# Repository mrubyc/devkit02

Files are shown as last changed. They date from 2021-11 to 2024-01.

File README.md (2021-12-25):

# ITOC謹製 mruby/c 開発ボード02

for mruby/c development kit 02 by ITOC.

## What is ?

ITOC (https://www.s-itoc.jp) で作成した mruby/c 開発リファレンスボード用リポジトリ。

マイコンは、Cypress PSoC5LP (CY8C5888LTI-LP097) であり、同社製のキット CY8CKIT-059 のピギーバックしているだけなので、素の CY8CKIT-059 に書き込んでも使える。

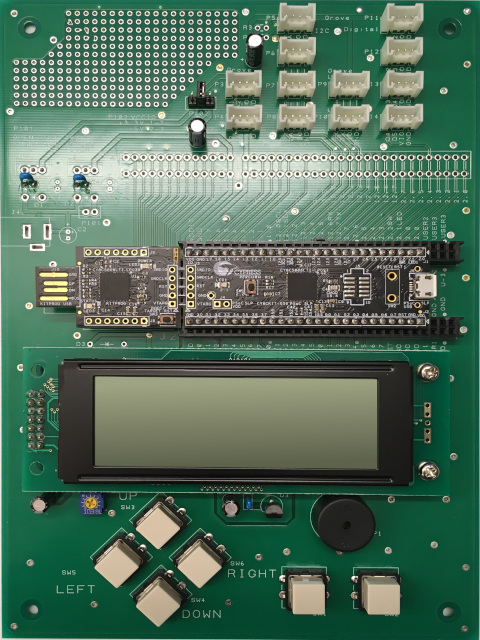
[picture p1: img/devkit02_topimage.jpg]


## Related Link

### Download IDE and others.
https://www.s-itoc.jp/activity/research/mrubyc/mrubyc_download/

### mrbwrite source code.
https://github.com/mrubyc/mrbwrite

### IDE source code.
comming soon.

### Device class source code.

https://github.com/mrubyc/dev

and I/O API proposal

https://github.com/mrubyc/dev/blob/master/mrubyc_io_api.md

### mruby/c sample code.

Some sample programs that mainly control sensors.

https://github.com/mrubyc/devkit02/tree/main/samples

## LICENSE

  Copyright (C) 2015-2021 Shimane IT Open-Innovation Center.

  All files in this repository are distributed under BSD 3-Clause License.

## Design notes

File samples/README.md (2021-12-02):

# Samples

mruby/c code sample with mruby/c devkit 02.

* GPIO
* A/D
* I2C with many sensors.

Most sensor sample programs work well on the Raspberry Pi.

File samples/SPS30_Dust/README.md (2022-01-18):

# SENSIRION SPS30

PM2.5 Sensor for HVAC and air quality applications

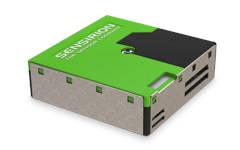
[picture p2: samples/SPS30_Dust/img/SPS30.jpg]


https://sensirion.com/products/catalog/SPS30/

## Connect to the board.

Connect to the glove I2C connector with a handmade bulk cable.

## Sample program

1. Use the I2C interface.
2. Reads PM2.5 and other size particle about once every second.
3. Display each measured value on the LCD panel (with scroll).

## Demo

https://user-images.githubusercontent.com/16683312/149897055-d63019b6-a0ee-472d-b40c-353299b3132d.mp4

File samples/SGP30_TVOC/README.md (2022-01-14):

# SENSIRION SGP30

Indoor Air Quality Sensor for TVOC and CO2eq Measurements

https://www.sensirion.com/en/environmental-sensors/gas-sensors/sgp30/

## Breakout board

to Grove connector; Seeed studio 101020512

https://www.seeedstudio.com/Grove-VOC-and-eCO2-Gas-Sensor-for-Arduino-SGP30.html

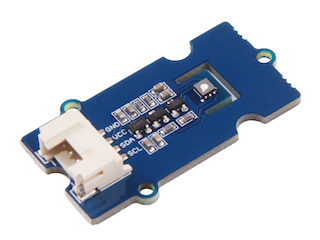
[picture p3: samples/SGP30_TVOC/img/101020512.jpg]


## Sample program

1. Use the I2C interface.
2. At first, wait 15 seconds for initializing sensor.
3. Reads VOC(TVOC) and CO2eq about once every second.

## Demo

https://user-images.githubusercontent.com/16683312/149466663-6540f6f8-e14d-4b3b-be49-4e50278e2f83.mp4

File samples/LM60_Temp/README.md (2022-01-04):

# Texas Instruments LM60

Temperature sensor.

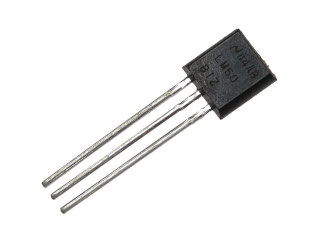
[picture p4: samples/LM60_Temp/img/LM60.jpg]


https://www.ti.com/product/LM60

mruby/c devkit 02 has LM60 temperature sensor on board.
This sensor has an analog output. 6.25 mV / ℃.

## Demo

https://user-images.githubusercontent.com/16683312/148042677-bf6fb1df-8735-4118-a3bd-9490f77eb376.mp4

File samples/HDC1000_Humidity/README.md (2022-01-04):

# Texas Instruments HDC1000

Digital Humidity Sensor with Integrated Temperature Sensor.

https://www.ti.com/product/HDC1000

## Breakout board

AkizukiDenshi AE-HDC1000.

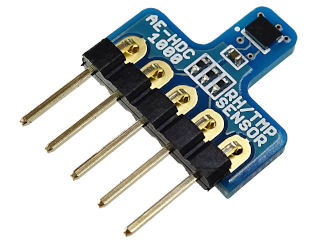
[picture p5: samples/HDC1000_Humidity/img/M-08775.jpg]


Connect a grove connector with soldering.

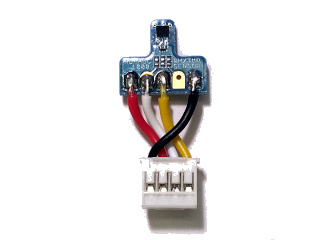
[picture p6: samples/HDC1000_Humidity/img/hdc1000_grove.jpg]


## Connect to the board.

Connect to the glove I2C connector.

## Sample program

1. Using I2C interface.
2. Reads temperature and humidity about once every second.

## Demo

https://user-images.githubusercontent.com/16683312/148039185-1c55f5a6-92fc-44ba-bbd0-9b33a6fce8e5.mp4

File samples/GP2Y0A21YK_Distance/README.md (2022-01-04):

# SHARP GP2Y0A21YK

Distance Measuring Sensor Unit.  
Measuring distance: 10 to 80 cm.  
Analog output type.

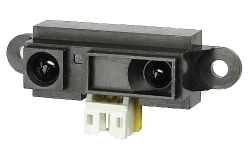
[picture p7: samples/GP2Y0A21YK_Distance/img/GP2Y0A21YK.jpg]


https://global.sharp/products/device/lineup/selection/opto/haca/diagram.html

## Connect to the board.

Connect to the glove analog connector with a handmade bulk cable.

## Sample program

1. Using Analog (A3) port.
2. Reads data with A/D API and display voltage value.
3. Also, when the voltage exceeds the threshold, LED1 is turned on to indicate that there is an object nearby. 

## Demo

https://user-images.githubusercontent.com/16683312/147382188-d99ca31b-5f03-4c57-91c4-038a6deff579.mp4

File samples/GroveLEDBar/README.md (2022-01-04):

# seeed studio Grove LED Bar v2.0

10 Segment LED Display using MY9221 12-Channel LED Driver

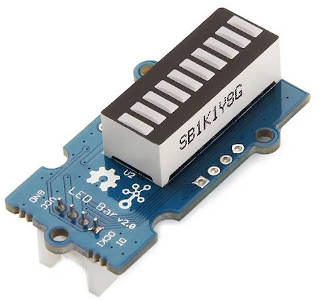
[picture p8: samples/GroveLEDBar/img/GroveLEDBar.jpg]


https://www.seeedstudio.com/Grove-LED-Bar-v2-0.html

## Sample program

Use as a level meter.
Also can specify the brightness of each LED individually.

## Demo

https://user-images.githubusercontent.com/16683312/147387371-79154d6b-c8f0-4d2c-b3c8-a75928846ea7.mp4

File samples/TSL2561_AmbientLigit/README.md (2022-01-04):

# ams (TAOS) TSL2561

Ambient Light Sensor

https://ams.com/tsl2561

## Breakout board

to Grove connector; Seeed studio 101020030

https://www.seeedstudio.com/Grove-Digital-Light-Sensor-TSL2561.html

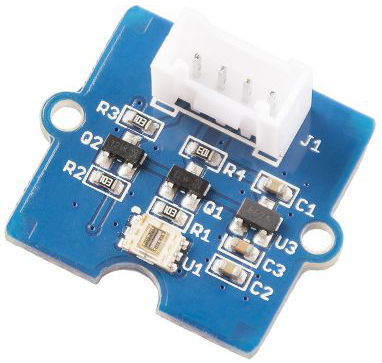
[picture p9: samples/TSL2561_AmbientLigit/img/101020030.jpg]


## Sample program

1. Use the I2C interface.
2. Use integration time 402ms and 101ms mode. (13.7ms mode is not used)
3. Automatically adjusts gain and integration time.

## Demo

https://user-images.githubusercontent.com/16683312/147381110-c7b632e3-6dce-4066-997e-5617c569e161.mp4

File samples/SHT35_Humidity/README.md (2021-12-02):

# Sensirion SHT35

Humidity and Temperature Sensor

https://www.sensirion.com/en/environmental-sensors/humidity-sensors/digital-humidity-sensors-for-various-applications/

## Breakout board

to Grove connector; Seeed studio 101020592

https://www.seeedstudio.com/Grove-I2C-High-Accuracy-Temp-Humi-Sensor-SHT35.html

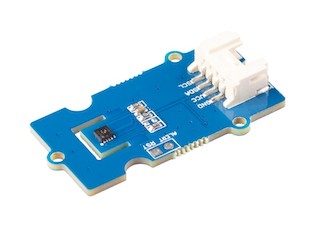
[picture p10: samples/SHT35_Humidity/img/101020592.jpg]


## Sample program

1. Using single shot mode with High repeatability clock stretching mode.
2. Reads about once every second.

## Demo

https://user-images.githubusercontent.com/16683312/144450023-0f474026-9f5d-40d5-b7ea-4d4efb06ff8f.mp4

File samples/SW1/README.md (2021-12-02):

# CY8C5888LTI-LP097 onboard switch SW1 ON and OFF demo.

## Abstruct

Cypress PSoC5LP Evaluation board CY8C5888LTI-LP097 onboard switch demo.

State of SW1 can be read by mruby/c method `sw1_read()`.

`sw1_read()` returns 0 when SW1 is pressed.

## Sample program

LED1 turns on when SW1 is pressed and turns off when released. 

## Demo

https://user-images.githubusercontent.com/16683312/144449586-0207ba0a-1b79-48ee-b7c4-c1c7ad308784.mp4

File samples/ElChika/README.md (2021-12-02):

# CY8C5888LTI-LP097 blink onboard LED.

## Abstruct

Cypress PSoC5LP Evaluation board CY8C5888LTI-LP097 onboard LED demo.

Blinking LED is often referred to as "el-chika" in Japan.

## Demo

https://user-images.githubusercontent.com/16683312/144448642-cc690b8e-6e4c-463b-ac18-35c6d1983098.mp4

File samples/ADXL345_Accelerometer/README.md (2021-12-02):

# ANALOG DEVICES ADXL345

Digital Accelerometer.

https://www.analog.com/en/products/adxl345.html

## Breakout board

https://akizukidenshi.com/catalog/g/gM-06724/

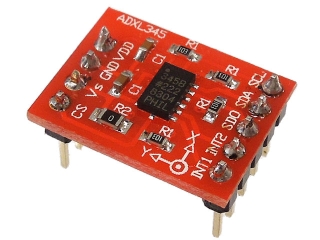
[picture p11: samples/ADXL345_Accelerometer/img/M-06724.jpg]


Set it on the breadboard and connect it to the glove connector with bulk wire.

## Sample program

1. Using I2C Interface.
2. Using Full resolution (16bit) mode.
3. Using ±2g measurement mode.

In one sample program, the measured value is represented by a bar that expands and contracts.

Another sample program simply emulates a ball rolling on a plane.

## Demo

main.rb

https://user-images.githubusercontent.com/16683312/144192729-ab362cf6-4b65-4aec-a082-47165c4c2c3b.mp4

main2.rb

https://user-images.githubusercontent.com/16683312/144194505-38d72f12-8f72-45bc-8e72-b4f3f158f905.mp4

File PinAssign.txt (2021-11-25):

[OnBoard]
LED1			P2[1]
SW1			P2[2]
Keypad			P0[0:5]
LCD			P15[0:5]
Thermo LM60		P3[0]
BUZZER			P3[6]
USB		Dm	P15[7]
		Dp	P15[6]
CONS		Rx	P12[6]
		Tx	P12[7]
SPI_1		MOSI	P1[2]
		MISO	P1[3]
		SCLK	P1[4]
		SS	P1[5]

[Grove]
ADC_SAR_1	Ana1	P3[1]
		Ana2	P3[3]
		Ana3	P3[5]

I2C_1		SCL	P12[0]
		SDA	P12[1]

UART_1		RX	P12[2]
		Tx	P12[3]

UART_2		RX	P12[4]
		Tx	P12[5]

GPIO		D1	P0[6]
		D2	P0[7]
		D3	P2[3]
		D4	P2[4]
		D5	P2[5]

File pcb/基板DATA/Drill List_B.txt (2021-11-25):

NC Drill Output
===============

    Output:
    ----------------------------
    Plated Round Drill Holes
    Unplated Round Drill Holes
    Plated Slots
    Unplated Slots

    Tool   Size        Count    ID   (Plated/Unplated)
    --------------------------------------------------
TH(スルーホール)
下記の穴径は、スルーホールメッキ後のサイズです。
穴径の公差指定の無い物は貴社の基準公差でお願いします。

    T001   000.300 mm  55     B
    T002   000.600 mm  26     I
    T003   000.601 mm  6      AI
      穴径0.6mmm でお願いします。

    T004   000.800 mm  273    O
    T005   000.801 mm  182    P
      J1,J2,J3,P3～P14のコネクタ用スルーホールです。
      穴径0.9mmm±0.1mm
      穴間公差±0.1mm でお願いします。

    T006   001.000 mm  5      E
    T007   001.001 mm  78     H
      穴径1.0mmm でお願いします。

    T008   001.002 mm  79     AH
      穴径1.0mmm でお願いします。

    T009   001.003 mm  2      AG
      SP1リード用スルーホール
      穴径1.0mmm±0.1mm でお願いします。
      穴間公差±0.1mm でお願いします。

    T010   001.010 mm  49     AF
      J4コネクタ用スルーホール(長穴)
      穴径1.0mmx3.2mm±0.1mm でお願いします。
      J4の他の穴間公差±0.1mm でお願いします。

    T011   001.011 mm  29     AX
      J4コネクタ用スルーホール(長穴)
      穴径1.0mmx3.8mm±0.1mm
      J4の他の穴間公差±0.1mm でお願いします。

    T012   001.200 mm  10     AE
    T013   001.201 mm  24     F
      SW1～6のリード用スルーホール
      穴径1.2mmm±0.1mm
      穴間公差±0.1mm でお願いします。

NTH(ノンスルーホール)
    T014   001.801 mm  12     G
      SW1～6の位置決め用の穴
      穴径1.90mm±0.1mm
      穴間公差9.0±0.1mm でお願いします。

    T015   003.200 mm  4      AD
      本基板のピギーバック基板固定用M3ねじバカ穴
      穴径3.2mm±0.1mm
      穴間公差±0.05mm でお願いします。

    T016   003.500 mm  4      AS
      本基板固定用M3ねじバカ穴
      穴径3.5mm±0.1mm
      穴間公差±0.1mm でお願いします。

    --------------------------------------------------
    Total              831

Drill Ident Drawing
===================

    Drill  Plated  Size   Shape  ID
    -------------------------------
    0.300  Y       2.540  Round  B
    1.000  Y       2.540  Round  E
    1.201  Y       2.540  Round  F
    1.801  Y       2.540  Round  G
    1.001  Y       2.540  Round  H
    0.600  Y       2.540  Round  I
    0.800  Y       2.540  Round  O
    0.801  Y       2.540  Round  P
    3.200  Y       2.540  Round  AD
    1.200  Y       2.540  Round  AE
    1.010  Y       2.540  Round  AF
    1.003  Y       2.540  Round  AG
    1.002  Y       2.540  Round  AH
    0.601  Y       2.540  Round  AI
    3.500  Y       2.540  Round  AS
    1.011  Y       2.540  Round  AX

    D-Code  Shape  (mm)
    -------------------
    D86     Round 2.540
    D87     Round 0.127

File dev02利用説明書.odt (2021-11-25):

mruby/c 評価ボード 02

利用説明書

2020/10/20 rev 1.0.0

しまねソフト研究開発センター

# ピンアサイン

ポート名 | タイプ | デバイス割り当て | （参考） CY8CKIT-059上のデバイス PSoC5内蔵デバイス
P0-0 | D-in | SW1 | OpAmp2.vout
P0-1 | D-in | SW2 | OPAmp0.vout
P0-2 | D-in | SW3 UP | C12 1u OpAmp0.v+, SAR1.ext
P0-3 | D-in | SW4 DOWN | C13 1u OpAmp0.v-, DSM0.ext1
P0-4 | D-in | SW5 LEFT | C9 1u OpAmp2.v+, SAR0.ext
P0-5 | D-in | SW6 RIGHT | OpAmp2.v-
P0-6 | D-Out | Grove GPIO D1 / PWM1 | VIDAC0.iout
P0-7 | D-I/O | Grove GPIO D2 | VIDAC2.iout
P1-0 | | (N/C) | PROG_SWDIO
P1-1 | | (N/C) | PROG_SWDCLK
P1-2 | | SPI MOSI
P1-3 | | SPI MISO | P_SWO
P1-4 | | SPI SCLK | P_TDI JTAG[0] tdi
P1-5 | | SPI SS | JTAG[0] ntrst
P1-6
P1-7
P2-0
P2-1 | D-out | (on-board LED1) | LED1
P2-2 | D-in | (on-board SW1) | SW1
P2-3 | D-I/O | Grove GPIO D3 | TRACE.CLK
P2-4 | D-I/O | Grove GPIO D4 | TRACE0.D0
P2-5 | D-I/O | Grove GPIO D5 | TRACE0.D1
P2-6 | | | TRACE0.D2
P2-7 | | | TRACE0.D3
P3-0 | A-in | U1 ThermoSensor TI LM60BIZ | VIDAC1.iout
P3-1 | A-in | Grove Analog A1 | VIDAC3.iout
P3-2 | | | C7 1u OpAmp3.v-, DSM0.ext2
P3-3 | A-in | Grove Analog A2 | OpAmp3.v+
P3-4 | | | OpAmp1.v-
P3-5 | A-in | Grove Analog A3 | OpAmp1.v+
P3-6 | | Piezoelectric Speaker (PWM0) | OpAmp1.vout
P3-7 | | (SP1-) | OpAmp3.vout
P12-0 | D-I/O | Grove I2C SCL | I2C1.scl
P12-1 | D-I/O | Grove I2C SDA | I2C1.sda
P12-2 | D-in | Grove UART1 RxD | SIO
P12-3 | D-out | Grove UART1 TxD | SIO
P12-4 | D-in | Grove UART2 RxD | I2C0.scl
P12-5 | D-out | Grove UART2 TxD | I2C0.sda
P12-6 | D-in | -------- | SIO RX (プログラマ経由ホストシリアル)
P12-7 | D-out | -------- | SIO TX (プログラマ経由ホストシリアル)
P15-0 | D-out | LCD DB4 (SC2004CS) | XTAL.xo
P15-1 | D-out | LCD DB5 | XTAL.xi
P15-2 | D-out | LCD DB6 | C42 22p XTAL32k.xo
P15-3 | D-out | LCD DB7 | C41 22p XTAL32k.xi
P15-4 | D-out | LCD E | C4 2200p
P15-5 | D-out | LCD RS
P15-6 | USB | -------- | USBIO dp (オンボードUSBマイクロコネクタ用)
P15-7 | USB | -------- | USBIO dm (オンボードUSBマイクロコネクタ用)

# mruby/c IDEの利用

提供された機能のみを使ってアプリケーションを構築する方法です。

統合開発環境、IDEを利用します。

あらかじめファームが書き込まれた本体を使用します。

## 接続

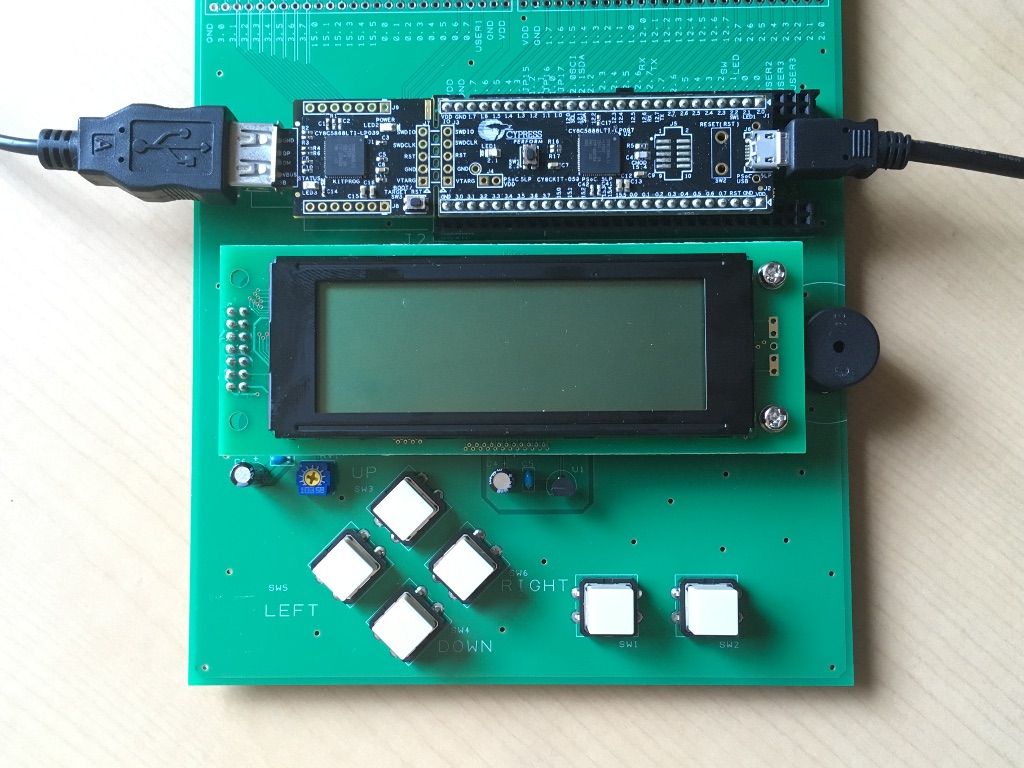
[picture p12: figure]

PCへ接続

(デバッグ用、

後で接続)

PCへ接続

(IDEで使用)

## IDE起動と設定

Windowsの例で説明しますが、MacやUNIXも同等です。

1. mrubyc-ide.exeを実行します。
2. File > Settings を選び、設定ダイアログを表示します。
3. 左ペインのBuild and Deployをクリックします。
4. 右ペインのCompilerタブで、LocalCompilerにチェックが入っていることを確認します
5. mrbc欄の[...]ボタンをクリックし、mrbc.exeのパスを指定します。
6. 右ペインのWriterタブに移り、同様にmrbwrite.exeのパスを指定します。
7. Port欄に、基板右サイドのマイクロUSB端子側の認識ポートを指定します。

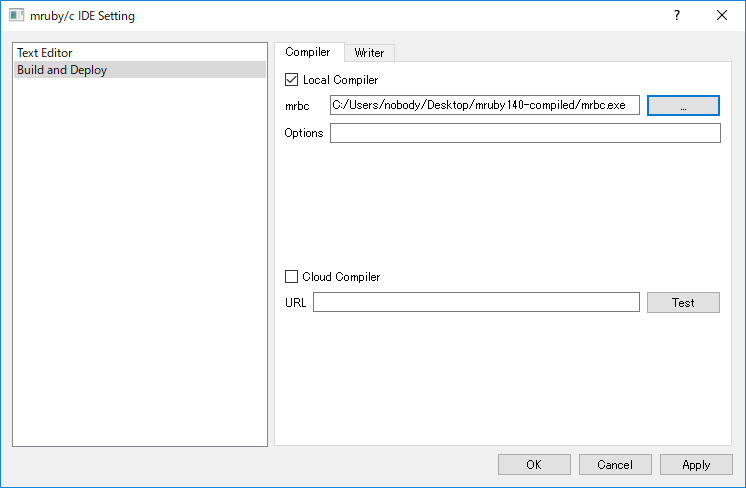
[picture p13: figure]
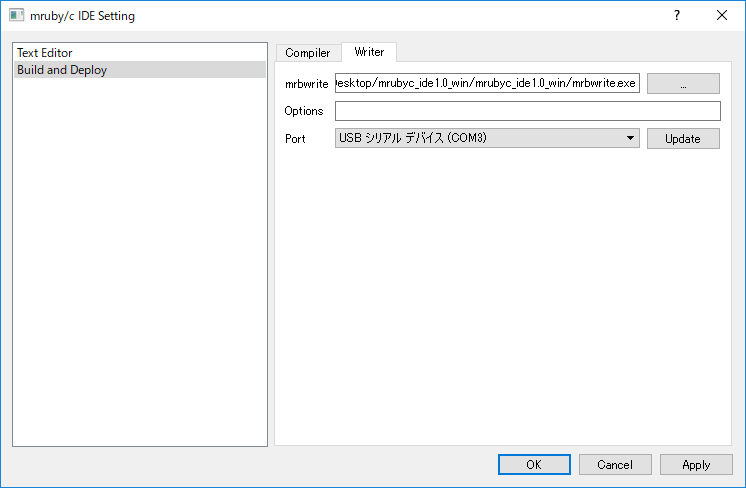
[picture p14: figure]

## デバグ用コンソールの起動（任意）

基板左サイドのUSB端子から、デバッグ用メッセージが表示されますので、開発時は接続しておくと便利です。

任意のターミナルソフトを利用して、ボーレート57600bpsで接続します。

## プログラムの編集と書き込み

1. File > New > Projectを選び、Setup New Projectダイアログを表示します。
2. 任意のプロジェクト名と、保存場所を指定します。
3. File > New > Fileを選び、Setup Add New Fileダイアログを表示します。
4. 任意のファイル名を指定します。

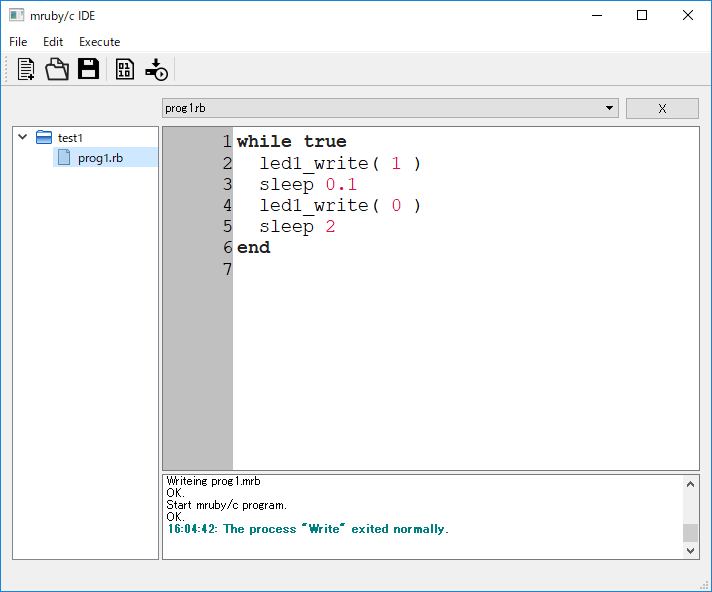
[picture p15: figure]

5. 右上のプログラムペインで、Rubyプログラムを編集します。
6. 編集が終わったら、Execute > Writeを選びます。
7. プログラムの書き込み待ち状態になるので、基板上のリセットスイッチを押下します。
8. プログラムが書き込まれ、動作開始します。

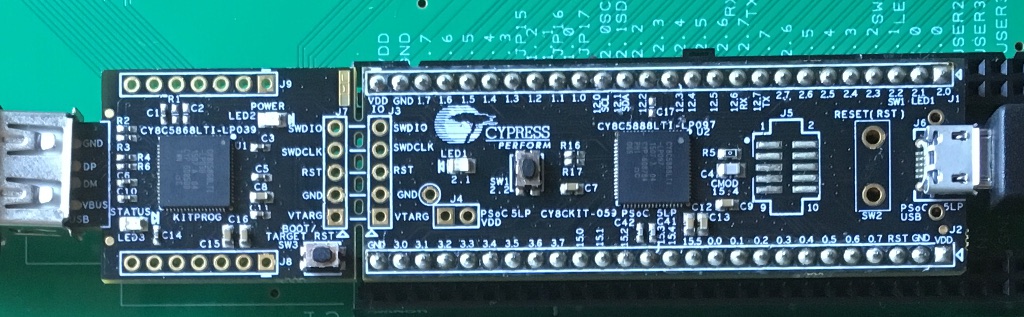
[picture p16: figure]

リセットスイッチ

# 利用できる機能

## オンボードスイッチ

マイコンドータ基板上のプッシュスイッチです。SW1のシルクがあります。

負論理で、0（押された）、1（押されていない）が、返ります。

sw1 = sw1_read()

## LED

マイコンドータ基板上の青色LEDです。LED1のシルクがあります。

正論理で、1（点灯）、0（消灯）です。

led1_write(1)

## キャラクタLCD表示器

4行×20文字のLCDパネルです。

アルファベットと数字、記号などが表示できます。詳しくは、HD44780のデータシート等を参照してください。

表示位置の指定

lcd_location( row, column )

1文字表示

lcd_putc( char_code )

文字列の表示

lcd_puts( "String" )

全画面消去

lcd_clear()

## キーパッド

メイン基板上の6個のタクトスイッチです。

ビットマップで全てのスイッチの押下状態を同時に確認できます。

負論理で、ビットは基板上シルクのSWxを参照してください。

key = keypad_read()

## 温度センサー

メイン基板上に、温度センサーLM60が搭載されており、温度の測定ができます。

詳細は、ADCの項を参照してください。

## GPIO

汎用のデジタル入出力です。GroveコネクタにD1からD5としてアサインしています。

D1は出力専用で、PWM1と共用です。

### コンストラクタ

### GPIO.new( n )

例

gpio1 = GPIO.new( 1 ) # param: grove pin number. 1 to 5.

### 入出力方向設定

### setmode( mode )

コンストラクタで指定したピンを、入力とするか出力とするかを指定します。

例

gpio1.setmode( GPIO::IN ) # GPIO::IN or GPIO::OUT

### 出力

### write( value )

例

gpio1.write( 1 )

### 入力

### read() -> Integer

例

val = gpio1.read() # val = 0 or 1

## ADC

汎用の電圧入力です。

A/Dコンバータ仕様

- 12ビット
- 0V - 2.048V
- 100000sps

### コンストラクタ

### ADC.new( n )

例

adc1 = ADC.new( 1 ) # param: grove pin number.

### 入力

### read() -> Float

例

val = adc1.read() # val = 0.0 - 2.048

### 温度センサー

メイン基板上に、温度センサーLM60が搭載されており、温度の測定ができます。

LM60は、アナログ値を出力します。本ボードでは、ADCのチャンネル0へ接続されています。

例

adc0 = ADC.new( 0 )

v = adc0.read()

t = (v - 424e-3) / 6.25e-3

## シリアル通信 UART

UARTシリアルインターフェースを扱います。

仕様

- ボーレート UART1 19200bps, UART2 9600bps
- 8bit, パリティーなし, スタートストップビット 1bit
- 5V

### コンストラクタ

### UART.new( n )

例

uart1 = UART.new( 1 ) # param: grove pin number.

### 出力

### write( string )

指定された文字列を出力します。

例

uart1.write("Output string¥r¥n")

### 入力

### read( n_bytes ) -> String, Nil

指定されたバイト数のデータを読み込みます。指定されたバイト数のデータが到着していない場合、nilを返します。

例

val = uart1.read( 10 )

（参考）通常、データが到着していなければブロックする方式が一般的ですが、mruby/cで作るアプリケーションの場合、あえてブロックしない方式としたほうがプログラミングしやすかったので、そのような仕様になっています。

### read_nonblock( maxlen ) -> String

指定されたバイト数のデータを読み込みます。指定されたバイト数のデータが到着していない場合、到着している分のデータを返します。

例

val = uart1.read_nonblock( 1024 )

### gets()

文字列を一行読み込みます。実際には受信キュー内の "\n" までのバイト列を返します。 受信キューに "\n" が無い場合、nilを返します。

例

val = uart1.gets()

（参考）受信キューより長い文字列を受信した場合、gets()では処理できません。その場合、受信キューを大きくしたファームウェアを用意する必要があります。

### その他

### clear_tx_buffer()

読み込みバッファをクリアします。

例

uart1.clear_tx_buffer()

### clear_rx_buffer()

書き込みバッファをクリアします。

例

uart1.clear_rx_buffer()

## シリアル通信 I2C

I2Cシリアルインターフェースを扱います。

仕様

- 5V
- 100kbps
- マスタモードのみ

### コンストラクタ

### I2C.new()

例

i2c = I2C.new()

### 出力

### write( i2c_adrs_7, data1, data2,... )

指定されたバイトを順次出力します。

例

i2c.write( ADRS, 0x02, 0x16, 0x00 )

### write( i2c_adrs_7, "string" )

指定された文字列を出力します。

例

i2c.write( ADRS, "string" )

### 入力

### read( i2c_adrs_7, read_bytes, *params ) -> String

指定されたバイト数のデータを読み込みます。指定されたバイト数のデータが到着していない場合、ブロックします。

paramsを指定することで、read前にparamsを出力します。すなわち、以下のシーケンスとなります。

(S) - ADRS7 (W)(A) - [params ...] - (Sr) - ADRS7 (R)(A) - data_1 (A)... data_n (A|N) - (P)

S : Start condition P : Stop condition

Sr: Repeated start condition

A : Ack N : Nack

例

s = i2c.read( ADRS, 2, 0xfe ) # 0xfeレジスタから2バイト取得

## シリアル通信 SPI

SPIシリアルインターフェースを扱います。

### コンストラクタ

### SPI.new()

例

spi = SPI.new()

### 出力

### write( data1, data2,... )

指定されたバイトを順次出力します。

例

spi.write( 0x02, 0x16, 0x00 )

### write( "string" )

指定された文字列を出力します。

例

spi.write( "string" )

### 入力

### read( read_bytes ) -> String

指定されたバイト数のデータを読み込みます。

例

s = spi.read( 2 )

### 汎用転送

### transfer( [d1, d2,...], recv_size ) -> String

d1,d2...を送信し、その後recv_size分の 0x00 を送信します。

戻り値は、受信した長さ recv_size バイトの文字列となります。

## パルス幅変調 PWM

パルス幅変調(Pulse Width Modulation)を扱います。 周波数を指定する方法と、周期を指定する方法があります。

本ボードでは、0番に圧電スピーカーを接続しています。１番は、GPIO1と出力ピンを共有しています。

### コンストラクタ

### PWM.new( n )

例

pwm = PWM.new(0)

### 周波数を指定する方法

### frequency( n )

指定した周波数の信号を出力します。最大値は利用する機器に依存します。0を指定すると出力を停止します。

### duty( n )

デューティー比を、0（全オフ）から1023（全オン）までで指定します。

例

pwm.frequency( 440 ) # 440Hz

pwm.duty( 512 ) # 50%

### 周期を指定する方法

### period_us( n )

周期を指定して信号を出力します。単位はマイクロ秒 (uS) です。 最大値は利用する機器に依存します。0を指定すると出力を停止します。

例

pwm.period_us( 2273 ) # 440Hz

pwm.duty( 512 ) # 50%

## Mutex

複数プログラムの同期用に、Mutexを使う事ができます。

$mutex1 = Mutex.new

$mutex1.lock()

$mutex1.unlock()

$mutex1.try_lock()

## その他のメソッド

mruby/cランタイムスケジューラには、以下のメソッドを用意しています。

### sleep( n )

実行一時停止。秒単位。

### sleep_ms( n )

実行一時停止。ミリ秒単位。

### relinquish()

他のタスクに実行を譲ります。

mruby/c devkit 02

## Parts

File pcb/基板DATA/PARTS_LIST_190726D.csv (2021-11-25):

Name | Component | メーカ | 数量 | Value | Side | Centre X | Centre Y | Rotation | 備考
------------------------------------------------------------------
C1 | RDER71H104K0P1H03B | MURATA | 1 | 0.1u | Top | 8.5 | 142.5 | 0
C2 | NOT USED | NOT USED | 1 | 100u | Top | 19.75 | 127.4 | 270
C3 | NOT USED | NOT USED | 1 | 100u | Top | 16.75 | 142.9 | 270
C4 | RDER71H104K0P1H03B | MURATA | 1 | 0.1u | Top | 23.75 | 142.5 | 0
C5 | 25PK100MEFC5X11 | Rubycon | 1 | 100u | Top | 73.6 | 181.5 | 0
C6 | NOT USED | NOT USED | 1 | 100u | Top | 32 | 142.9 | 270
C7 | 25PK100MEFC5X11 | Rubycon | 1 | 100u | Top | 57.75 | 157.4 | 270
C8 | RDER71H104K0P1H03B | MURATA | 1 | 0.1u | Top | 57.13 | 114.3 | 0
C9 | RDER71H104K0P1H03B | MURATA | 1 | 0.1u | Top | 118.13 | 103.505 | 180
C10 | RDER71H104K0P1H03B | MURATA | 1 | 0.1u | Top | 19.665 | 47.625 | 0
C11 | 25PK100MEFC5X11 | Rubycon | 1 | 100u | Top | 13.97 | 45.1 | 270
C12 | 25PK100MEFC5X11 | Rubycon | 1 | 100u | Top | 67.31 | 43.83 | 270
C13 | RDER71H104K0P1H03B | MURATA | 1 | 0.1u | Top | 72.39 | 43.2 | 270
D1 | NOT USED | NOT USED | 1 |  | Top | 9.75 | 138.5 | 0
D2 | NOT USED | NOT USED | 1 |  | Top | 25 | 138.5 | 0
D3 | NOT USED | NOT USED | 1 |  | Top | 31 | 92.5 | 0
D4 | NOT USED | NOT USED | 1 |  | Top | 31 | 89.25 | 0
D5 | NOT USED | NOT USED | 1 |  | Top | 31 | 86.25 | 0
D6 | NOT USED | NOT USED | 1 |  | Top | 41 | 83 | 180
D7 | NOT USED | NOT USED | 1 |  | Top | 41 | 79.75 | 180
D8 | NOT USED | NOT USED | 1 |  | Top | 41 | 76.5 | 180
J1 | XG4H-6031 | OMRON | 1 |  | Top | 92.71 | 120.65 | 0
J1B | XG4Z-0005 | OMRON | 1 |  |  |  |  |  | J1の57番に誤挿入防止ピン1本
J2 | XG4H-6031 | OMRON | 1 |  | Top | 92.71 | 97.79 | 0
J2B | XG4Z-0005 | OMRON | 1 |  |  |  |  |  | J2の27番に誤挿入防止ピン1本
J3 | XG4H-1431 | OMRON | 1 |  | Top | 12.701 | 69.85 | 90 | FH-2x07SG | Useconn Electronics Ltd.
J4 | NOT USED | NOT USED | 1 |  | Top | 7.349 | 127.051 | 0
P1a | NOT USED | NOT USED | 1 |  | Top | 103.505 | 151.13 | 0
P1b | NOT USED | NOT USED | 1 |  | Top | 103.505 | 146.05 | 0
P2a | NOT USED | NOT USED | 1 |  | Top | 52.07 | 151.13 | 0
P2b | NOT USED | NOT USED | 1 |  | Top | 52.07 | 146.05 | 0
P3 | 1125S-4P | SHENZHEN NS-TECH | 1 |  | Top | 71 | 172.264 | 0 | SEED 110990030
P4 | 1125S-4P | SHENZHEN NS-TECH | 1 |  | Top | 71 | 162.264 | 0 | SEED 110990030
P5 | 1125S-4P | SHENZHEN NS-TECH | 1 |  | Top | 86 | 192.264 | 0 | SEED 110990030
P6 | 1125S-4P | SHENZHEN NS-TECH | 1 |  | Top | 86 | 182.264 | 0 | SEED 110990030
P7 | 1125S-4P | SHENZHEN NS-TECH | 1 |  | Top | 86 | 172.264 | 0 | SEED 110990030
P8 | 1125S-4P | SHENZHEN NS-TECH | 1 |  | Top | 86 | 162.264 | 0 | SEED 110990030
P9 | 1125S-4P | SHENZHEN NS-TECH | 1 |  | Top | 101 | 172.264 | 0 | SEED 110990030
P10 | 1125S-4P | SHENZHEN NS-TECH | 1 |  | Top | 101 | 162.264 | 0 | SEED 110990030
P11 | 1125S-4P | SHENZHEN NS-TECH | 1 |  | Top | 116 | 192.264 | 0 | SEED 110990030
P12 | 1125S-4P | SHENZHEN NS-TECH | 1 |  | Top | 116 | 182.264 | 0 | SEED 110990030
P13 | 1125S-4P | SHENZHEN NS-TECH | 1 |  | Top | 116 | 172.264 | 0 | SEED 110990030
P14 | 1125S-4P | SHENZHEN NS-TECH | 1 |  | Top | 116 | 162.264 | 0 | SEED 110990030
P101 | NOT USED | NOT USED | 1 |  | Top | 26.23 | 134 | 90
P101b | NOT USED | NOT USED
P102 | XG8S-0331 | OMRON | 1 |  | Top | 58.75 | 168 | 90 | PH-1x03SG | Useconn Electronics Ltd.
P102ｂ | XJ8A-0211 | OMRON |  |  |  |  |  |  | MJ-254-6BK | Useconn Electronics Ltd.
R1 | 1/4W 1kΩ |  | 1 | 1k | Top | 83.296 | 77.362 | 315 | リード付きの1/4W抵抗
R2 | NOT USED | NOT USED | 1 | 1k | Top | 85.046 | 68.112 | 315
R3 | NOT USED | NOT USED | 1 | 1k | Top | 76.52 | 191.25 | 0
R4 | NOT USED | NOT USED |  | 1k | Top | 76.52 | 188.25 | 0
RV1 | CT-6EP10kΩ(103) | COPAL | 1 | 10k | Top | 27.305 | 43.815 | 0
SP1 | PKM17EPP-2002-B0 | MURATA | 1 |  | Top | 99.25 | 38.5 | 90
SW1 | B3F-4050 | OMRON | 1 |  | Top | 88.8 | 16.491 | 180
SW1b | B32-1200 | OMRON | 1 |  |  |  |  |  | 再利用
SW2 | B3F-4050 | OMRON | 1 |  | Top | 109.755 | 16.491 | 180
SW2b | B32-1200 | OMRON | 1 |  |  |  |  |  | 再利用
SW3 | B3F-4050 | OMRON | 1 |  | Top | 46.776 | 37.224 | 45
SW3b | B32-1200 | OMRON | 1 |  |  |  |  |  | 再利用
SW4 | B3F-4050 | OMRON | 1 |  | Top | 46.86 | 14.14 | 225
SW4b | B32-1200 | OMRON | 1 |  |  |  |  |  | 再利用
SW5 | B3F-4050 | OMRON | 1 |  | Top | 35.276 | 25.724 | 45
SW5b | B32-1200 | OMRON | 1 |  |  |  |  |  | 再利用
SW6 | B3F-4050 | OMRON | 1 |  | Top | 58.36 | 25.64 | 225
SW6b | B32-1200 | OMRON | 1 |  |  |  |  |  | 再利用
U1 | NOT USED | NOT USED | 1 | 3.3V | Top | 9.75 | 147.318 | 0
U2 | NOT USED | NOT USED | 1 | 5V | Top | 25 | 147.318 | 0
U3 | LM60BIZ | TI/BB/NS | 1 |  | Top | 79.375 | 42.545 | 180
------------------------------------------------------------------
J1B,J2Bの「XG4Z-0005」は、4本入りであり、それぞれ1本づつ使用する。

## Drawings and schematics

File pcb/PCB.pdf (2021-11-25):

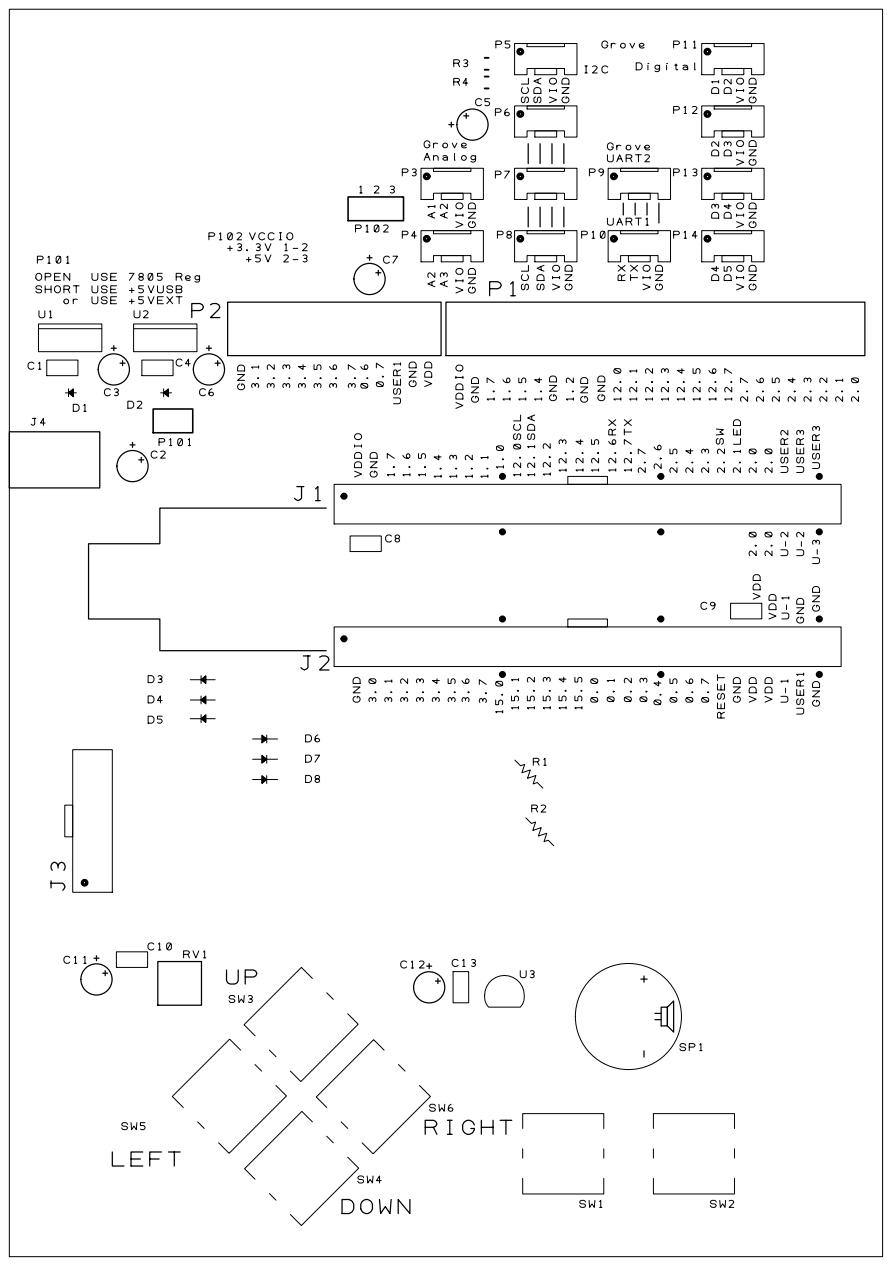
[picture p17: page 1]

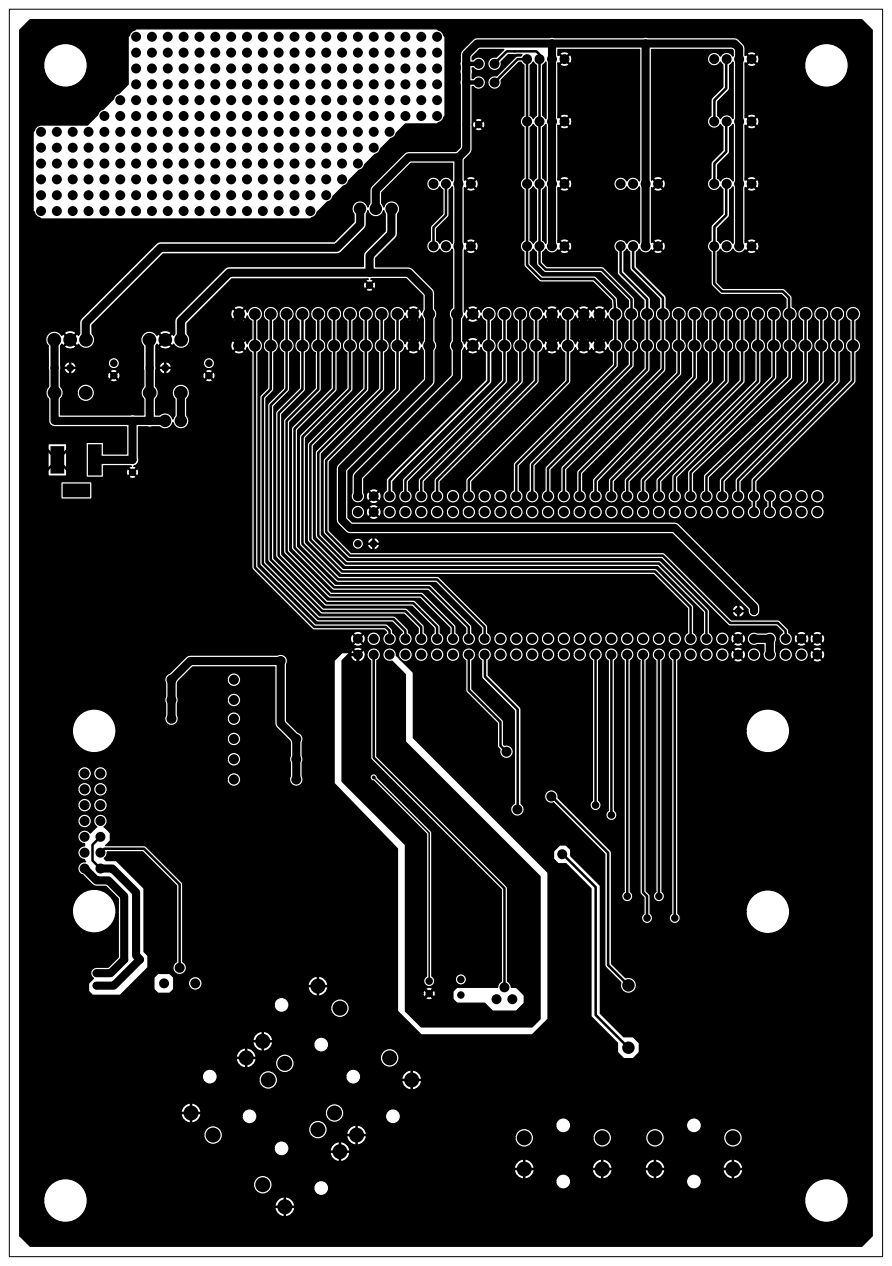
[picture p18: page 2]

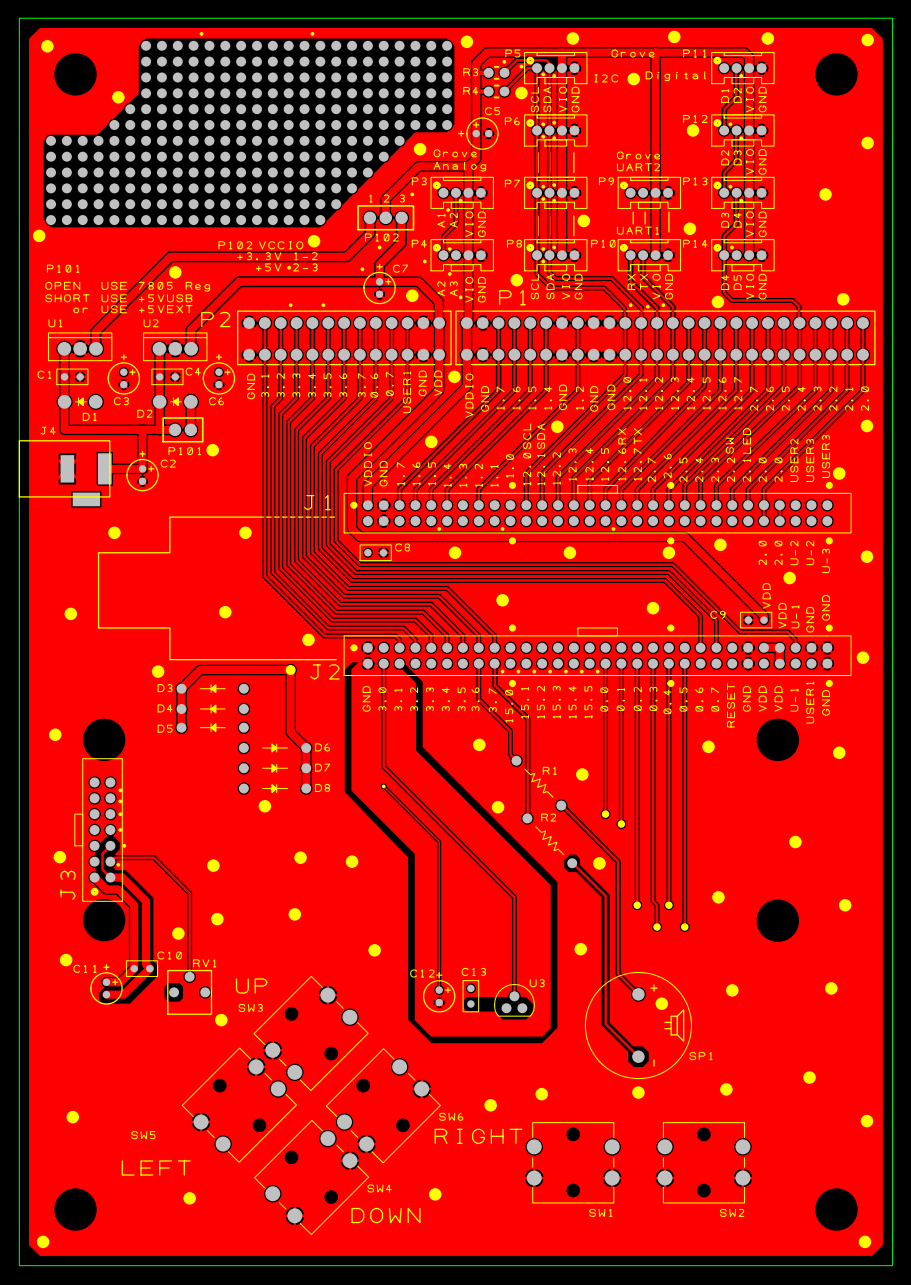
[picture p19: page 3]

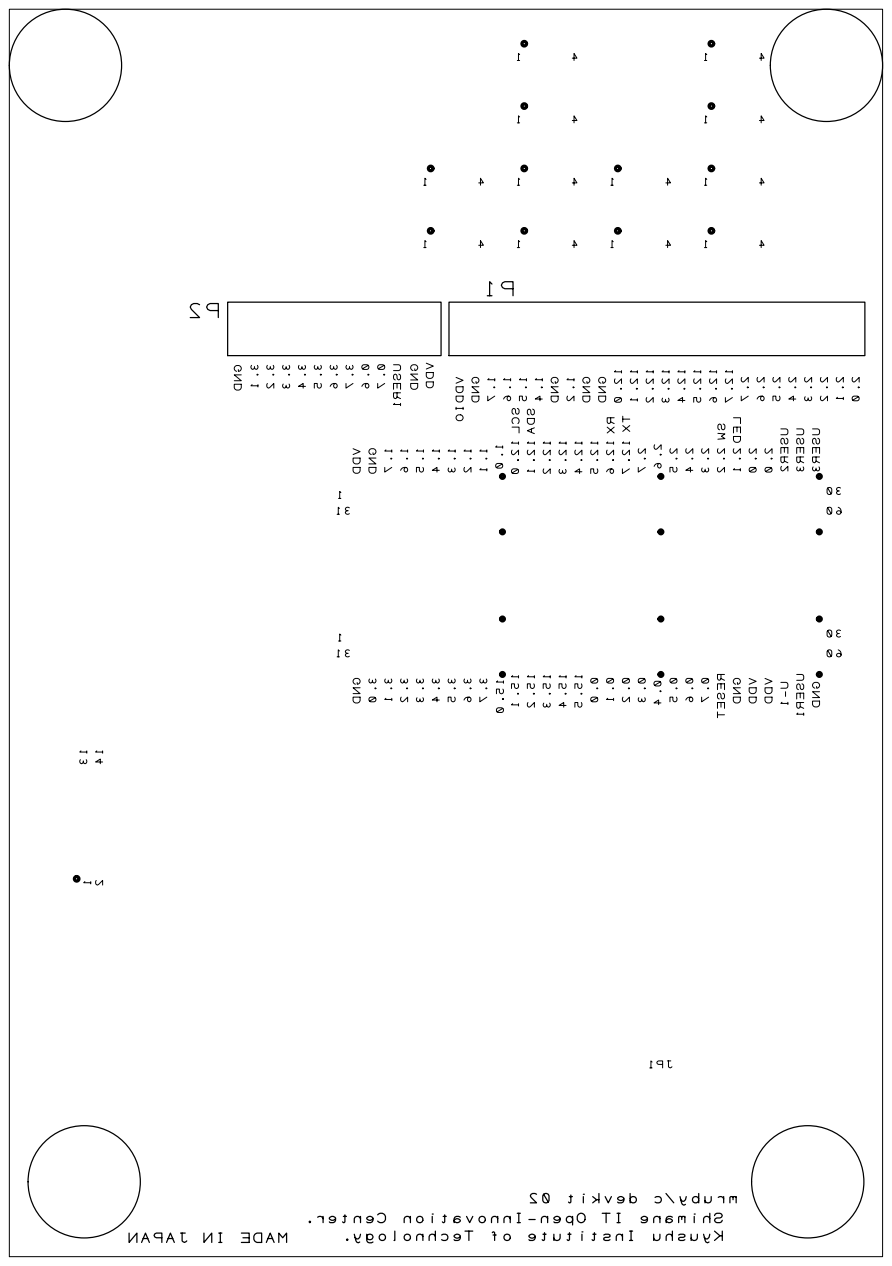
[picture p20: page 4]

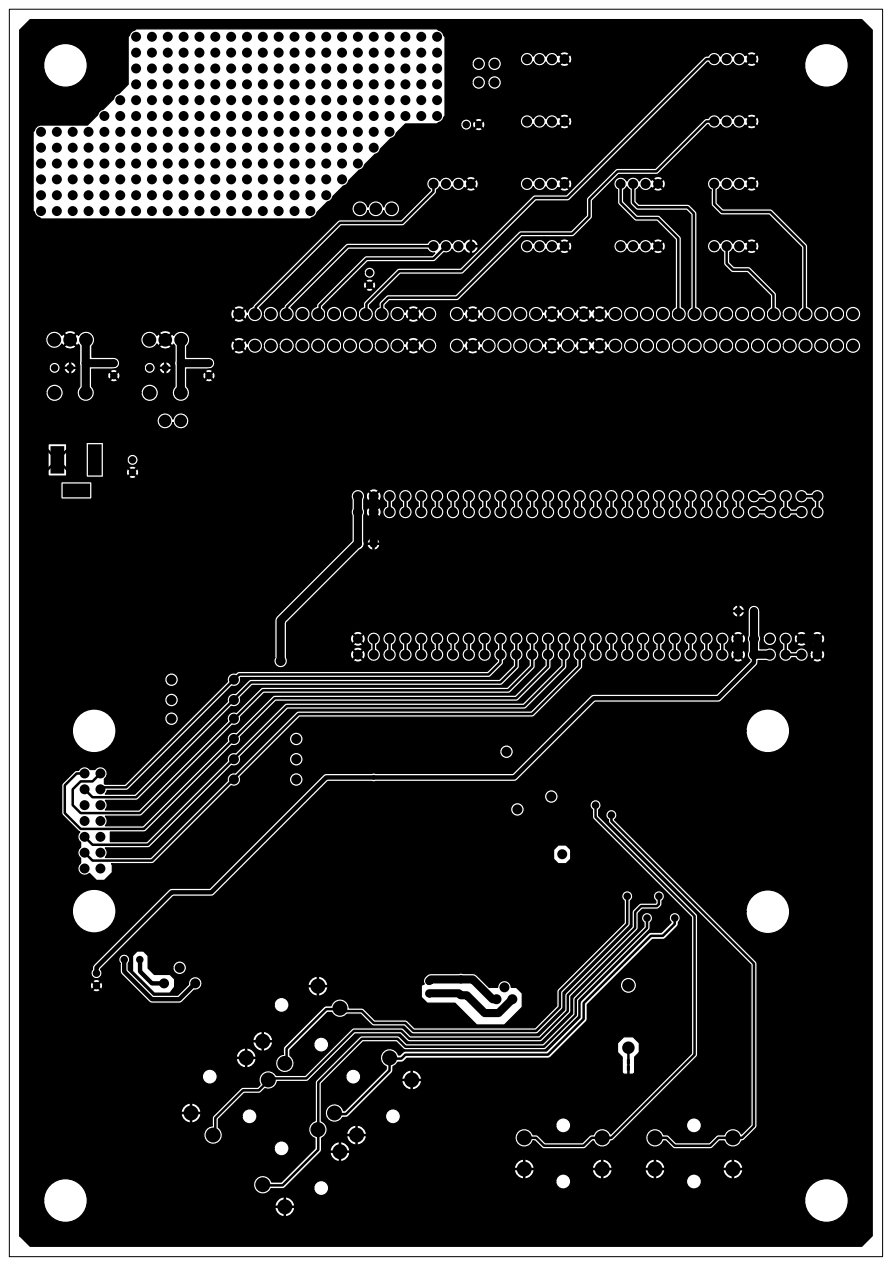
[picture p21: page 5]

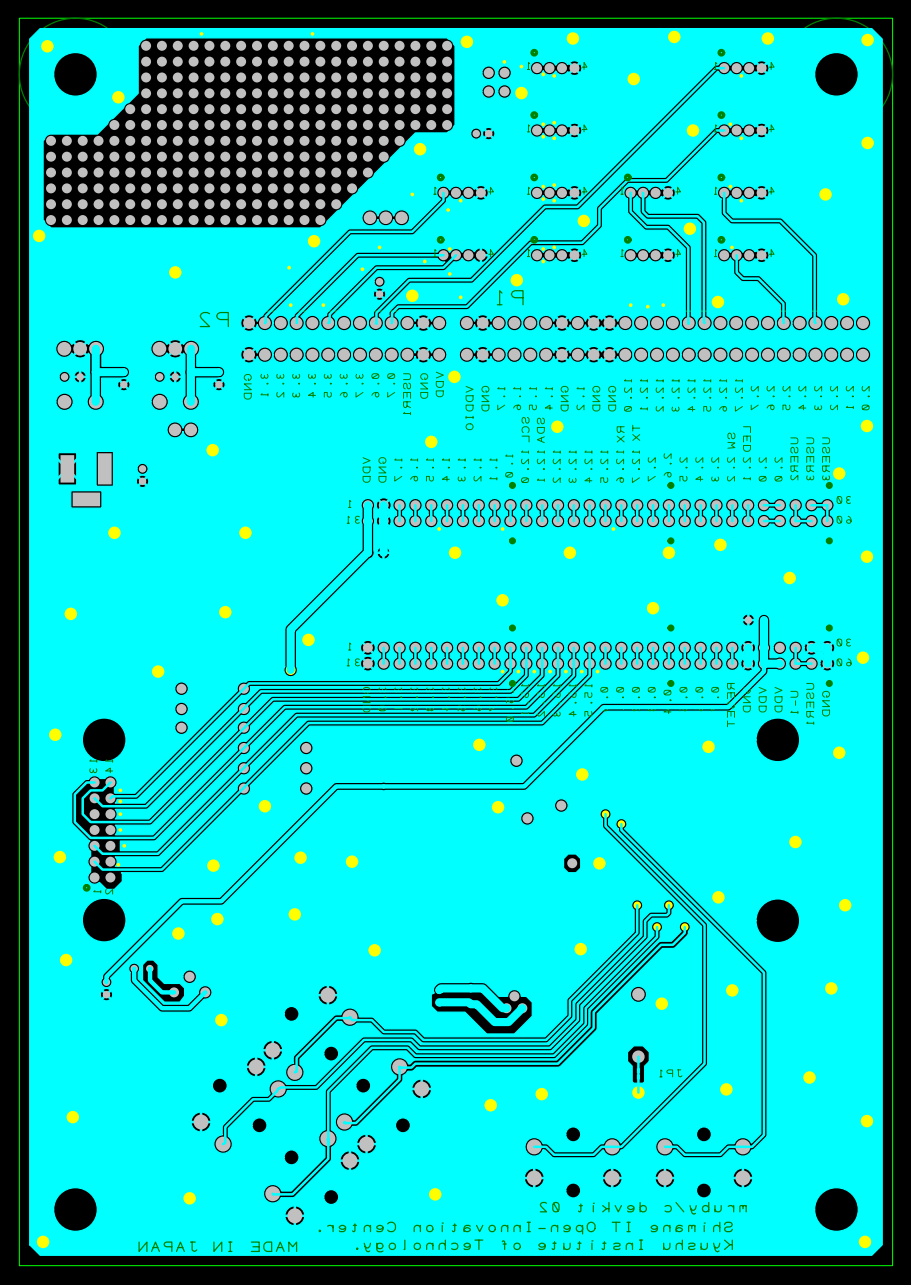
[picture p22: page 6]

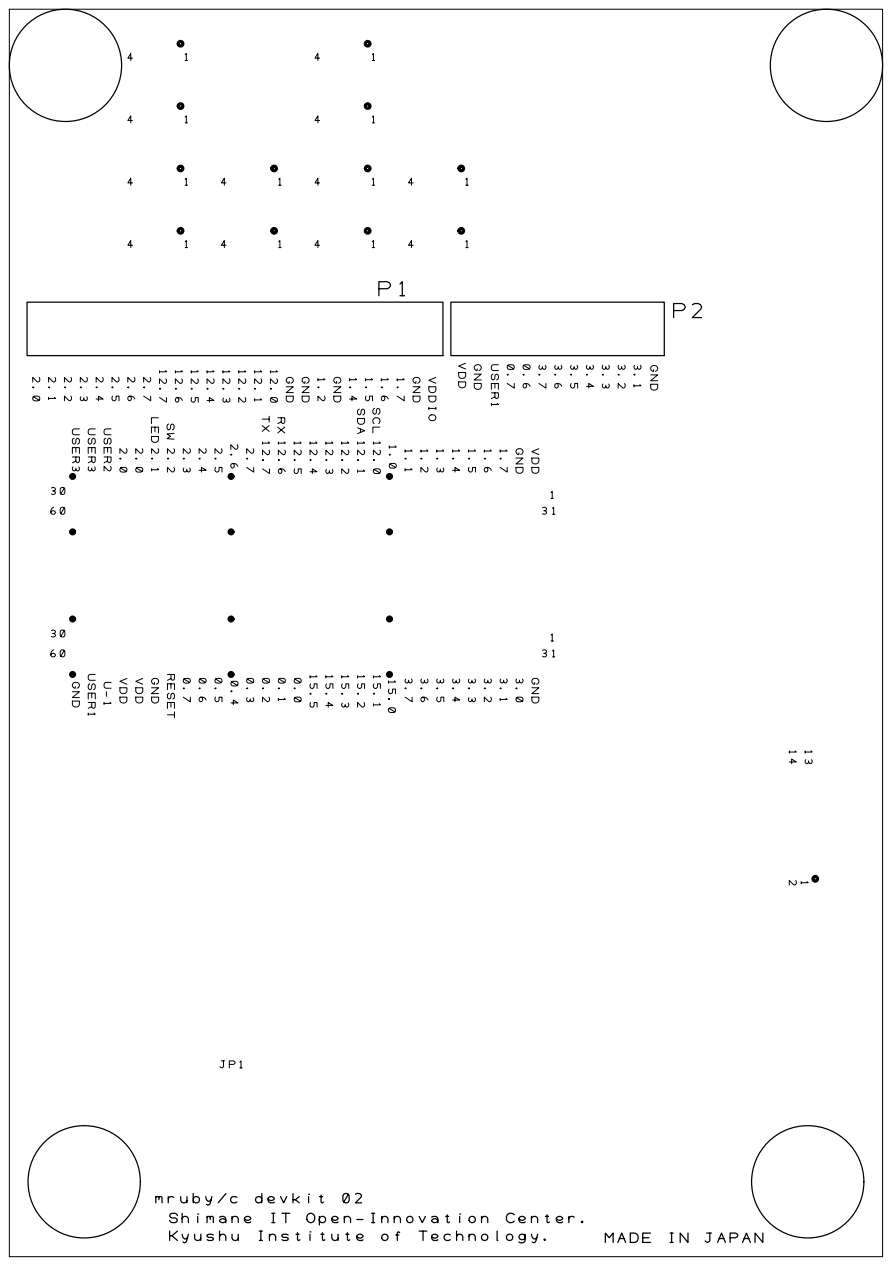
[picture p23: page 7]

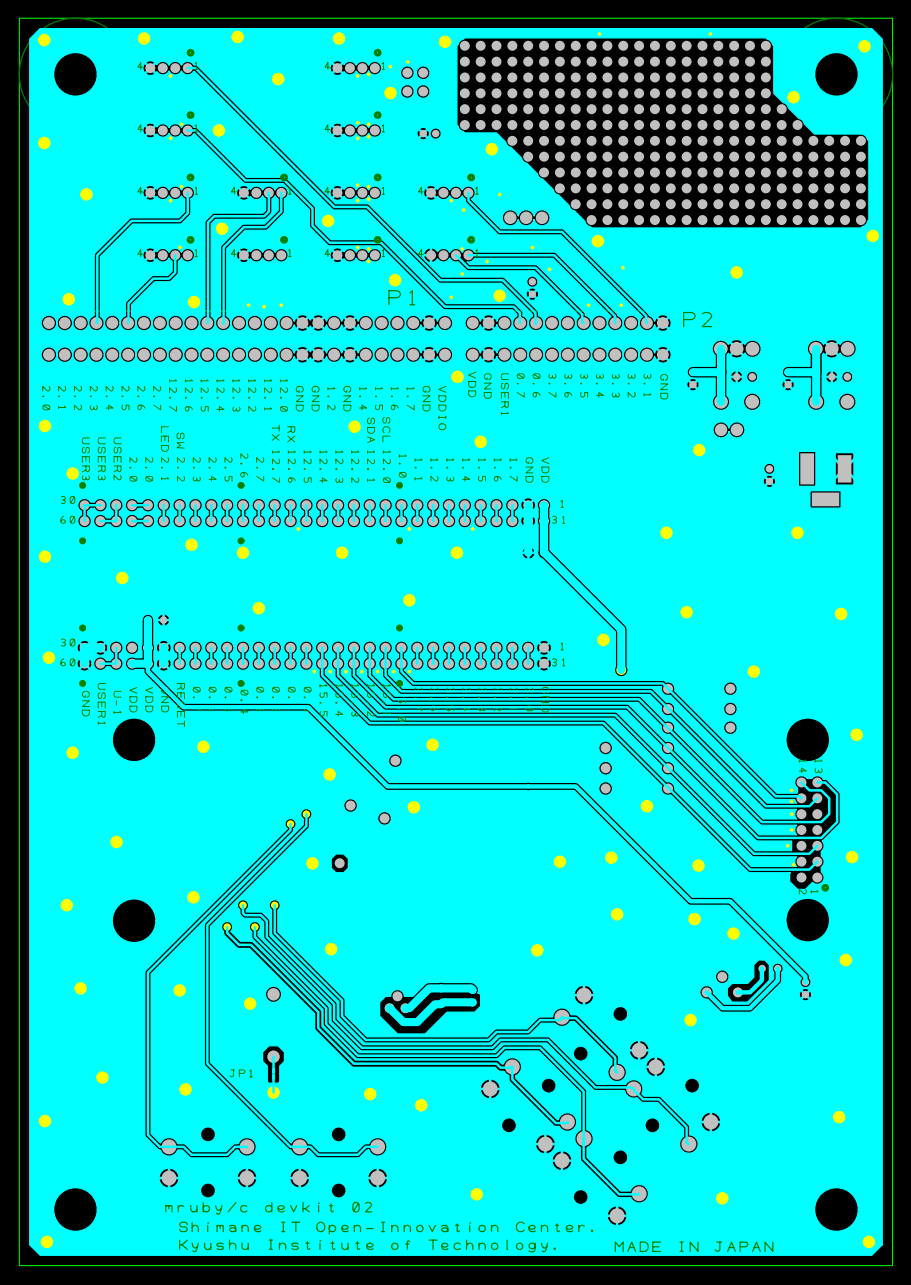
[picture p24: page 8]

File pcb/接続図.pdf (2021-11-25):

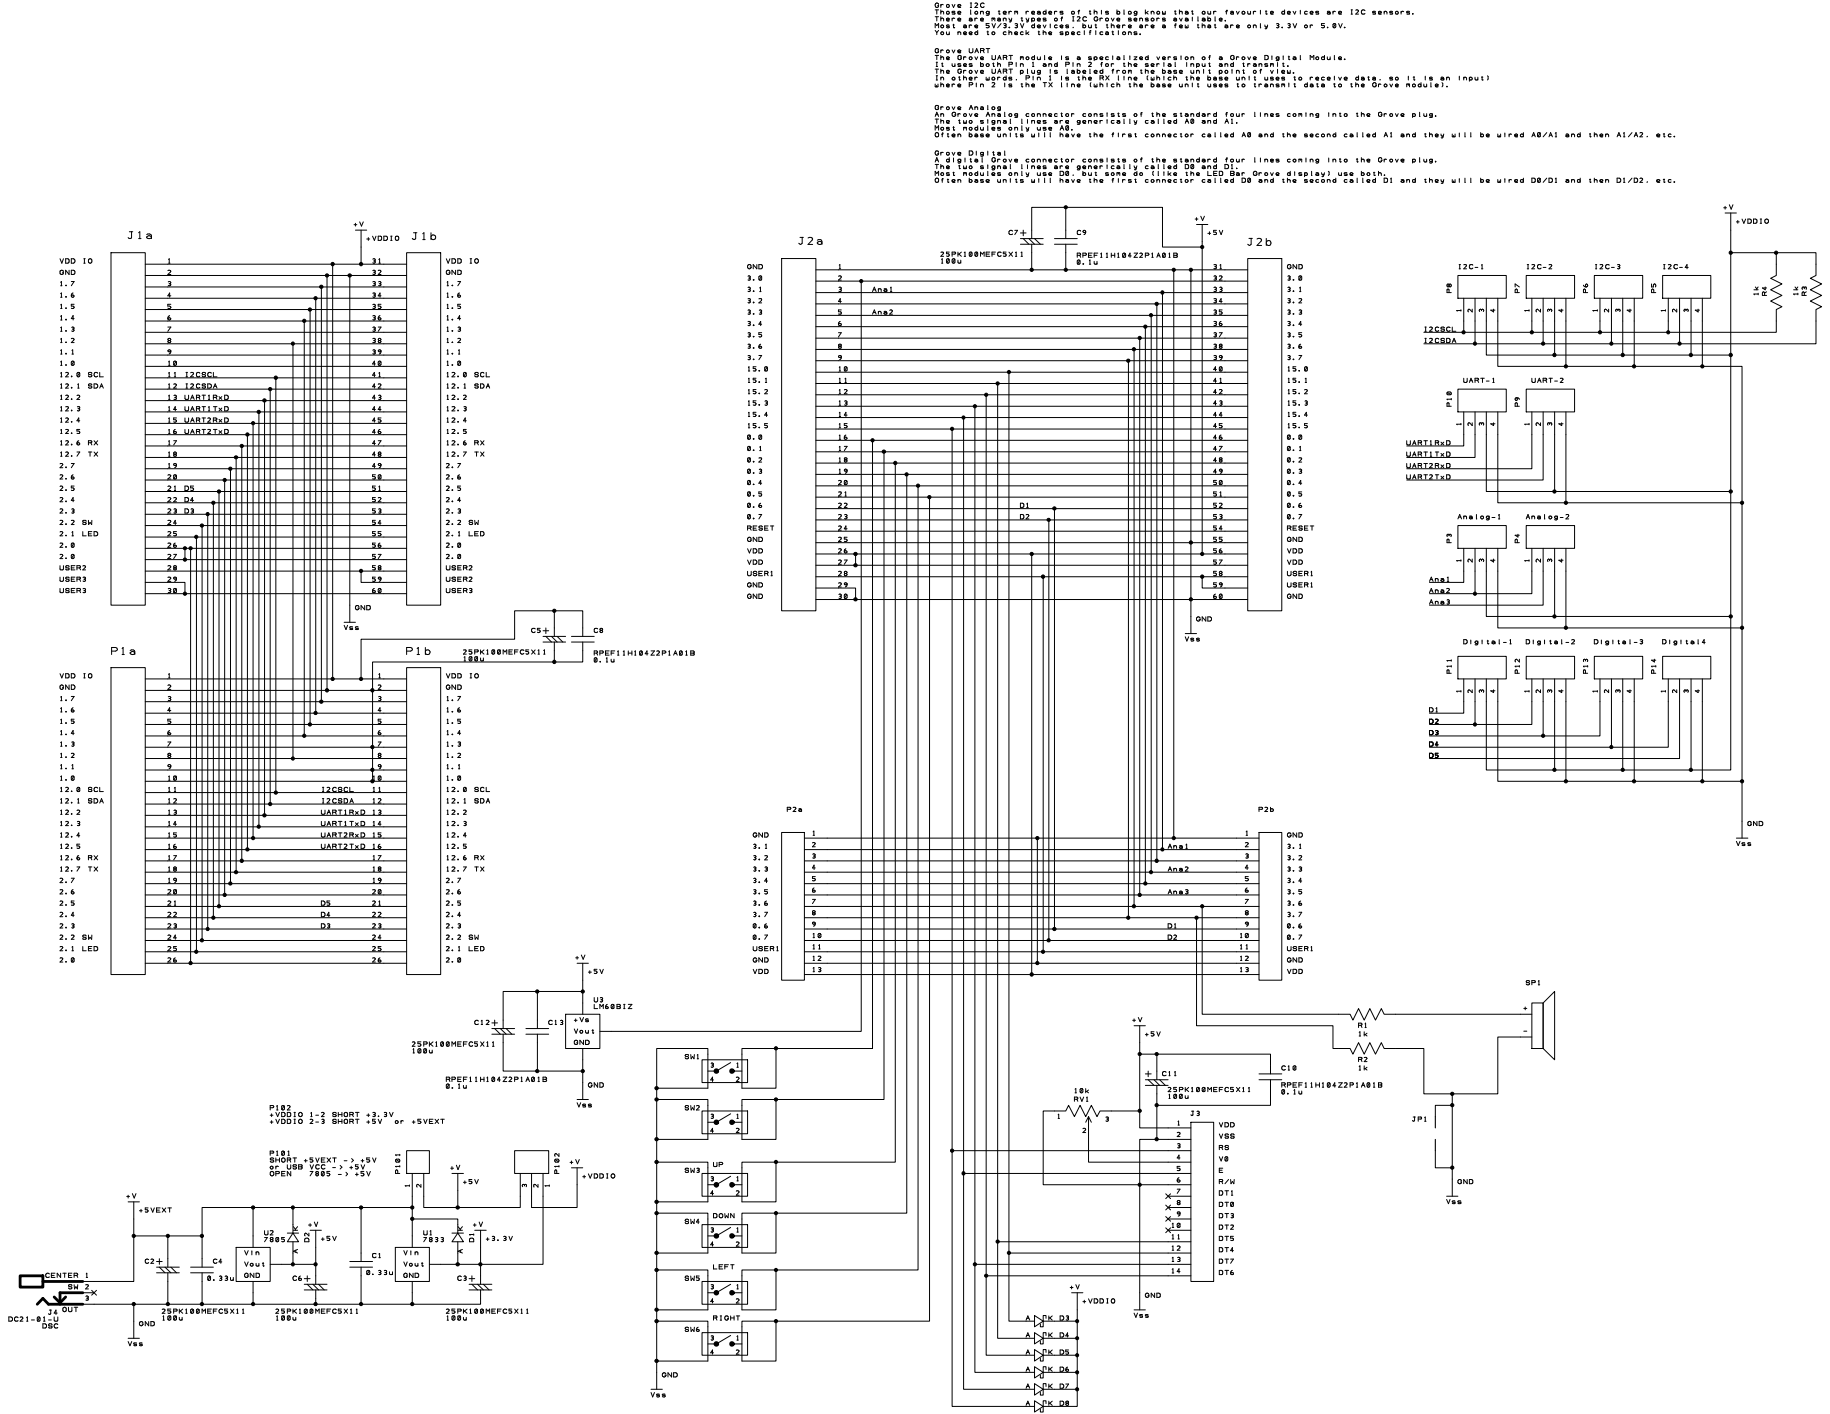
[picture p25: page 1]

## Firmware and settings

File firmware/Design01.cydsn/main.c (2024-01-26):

/*! @file
  @brief
  mruby/c firmware for mruby/c devkit 02

  <pre>
  Copyright (C) 2018-2021 Kyushu Institute of Technology.
  Copyright (C) 2018-2021 Shimane IT Open-Innovation Center.

  This file is distributed under BSD 3-Clause License.

  </pre>
*/


#include <project.h>
#include <stdint.h>
#include <stdio.h>
#include <stdlib.h>

#include "mrubyc.h"
#include "lcdc.h"
#include "c_i2c.h"
#include "c_uart.h"
#include "c_spi.h"
#include "c_eeprom.h"

#include "mrbc_monitor.h"


#define PWM_FREQ 2400000
#define PWM_COUNT_MAX 65535

#define MEMORY_SIZE (1024*32)	// mruby/c workarea.
static uint8_t memory_pool[MEMORY_SIZE];


/* Flash ROM structure.
  (e.g. MRBC_MAX_BYTECODES = 4)
 0000 size1	(uint16_t * 4)
 0002 size2
 0004 size3
 0006 size4
 0008 IREP1	(size1 bytes)
 xxxx IREP2	(size2 bytes)
 xxxx IREP3	(size3 bytes)
 xxxx IREP4	(size4 bytes)
*/
const uint8_t CYCODE mruby_bytecode[MRBC_SIZE_IREP_STRAGE] = {
  0xf8,0xff, 0,0, 0,0, 0,0,

0x52,0x49,0x54,0x45,0x30,0x30,0x30,0x36,0x8c,0xf9,0x00,0x00,0x02,0x4e,0x4d,0x41,
0x54,0x5a,0x30,0x30,0x30,0x30,0x49,0x52,0x45,0x50,0x00,0x00,0x02,0x30,0x30,0x30,
0x30,0x32,0x00,0x00,0x03,0xa1,0x00,0x07,0x00,0x0f,0x00,0x01,0x00,0x00,0x00,0xbd,
0x10,0x07,0x06,0x08,0x06,0x09,0x2e,0x07,0x00,0x02,0x10,0x07,0x4f,0x08,0x00,0x2e,
0x07,0x01,0x01,0x4f,0x07,0x01,0x08,0x08,0x03,0x09,0x0c,0x46,0x07,0x03,0x4f,0x08,
0x02,0x08,0x09,0x03,0x0a,0x10,0x46,0x08,0x03,0x4f,0x09,0x03,0x07,0x0a,0x0b,0x0b,
0x46,0x09,0x03,0x4f,0x0a,0x04,0x09,0x0b,0x0b,0x0c,0x46,0x0a,0x03,0x4f,0x0b,0x05,
0x08,0x0c,0x07,0x0d,0x46,0x0b,0x03,0x4f,0x0c,0x06,0x08,0x0d,0x0c,0x0e,0x46,0x0c,
0x03,0x46,0x07,0x06,0x01,0x01,0x07,0x06,0x02,0x06,0x03,0x06,0x04,0x21,0x00,0xb2,
0x01,0x07,0x03,0x3c,0x07,0x01,0x01,0x03,0x07,0x0c,0x08,0x2e,0x07,0x02,0x01,0x07,
0x08,0x2e,0x07,0x03,0x01,0x01,0x02,0x07,0x10,0x07,0x01,0x08,0x02,0x2e,0x07,0x04,
0x01,0x10,0x07,0x2e,0x07,0x05,0x00,0x01,0x05,0x07,0x2e,0x07,0x06,0x00,0x03,0x08,
0x3f,0x2e,0x07,0x03,0x01,0x01,0x05,0x07,0x01,0x08,0x04,0x2e,0x07,0x07,0x01,0x01,
0x06,0x07,0x01,0x07,0x01,0x55,0x08,0x00,0x2f,0x07,0x08,0x00,0x01,0x07,0x05,0x01,
0x04,0x07,0x11,0x07,0x22,0x07,0x00,0x60,0x0f,0x07,0x37,0x07,0x67,0x00,0x00,0x00,
0x07,0x00,0x00,0x11,0x6d,0x72,0x75,0x62,0x79,0x2f,0x63,0x20,0x64,0x65,0x76,0x6b,
0x69,0x74,0x20,0x30,0x32,0x00,0x00,0x03,0x53,0x57,0x31,0x00,0x00,0x03,0x53,0x57,
0x32,0x00,0x00,0x02,0x55,0x50,0x00,0x00,0x04,0x44,0x4f,0x57,0x4e,0x00,0x00,0x04,
0x4c,0x45,0x46,0x54,0x00,0x00,0x05,0x52,0x49,0x47,0x48,0x54,0x00,0x00,0x00,0x09,
0x00,0x0c,0x6c,0x63,0x64,0x5f,0x6c,0x6f,0x63,0x61,0x74,0x69,0x6f,0x6e,0x00,0x00,
0x08,0x6c,0x63,0x64,0x5f,0x70,0x75,0x74,0x73,0x00,0x00,0x02,0x3e,0x3e,0x00,0x00,
0x01,0x26,0x00,0x00,0x0a,0x6c,0x65,0x64,0x31,0x5f,0x77,0x72,0x69,0x74,0x65,0x00,
0x00,0x0b,0x6b,0x65,0x79,0x70,0x61,0x64,0x5f,0x72,0x65,0x61,0x64,0x00,0x00,0x01,
0x7e,0x00,0x00,0x01,0x5e,0x00,0x00,0x0f,0x65,0x61,0x63,0x68,0x5f,0x77,0x69,0x74,
0x68,0x5f,0x69,0x6e,0x64,0x65,0x78,0x00,0x00,0x00,0x02,0x1f,0x00,0x04,0x00,0x09,
0x00,0x00,0x00,0x00,0x00,0x75,0x00,0x00,0x33,0x08,0x00,0x00,0x1f,0x04,0x06,0x00,
0x07,0x05,0x01,0x06,0x02,0x2e,0x05,0x00,0x01,0x2e,0x04,0x01,0x01,0x06,0x05,0x41,
0x04,0x23,0x04,0x00,0x21,0x0f,0x04,0x37,0x04,0x10,0x04,0x01,0x05,0x01,0x07,0x06,
0x2e,0x05,0x02,0x01,0x01,0x06,0x01,0x08,0x07,0x2e,0x06,0x02,0x01,0x2e,0x04,0x03,
0x02,0x1f,0x04,0x05,0x00,0x07,0x05,0x01,0x06,0x02,0x2e,0x05,0x00,0x01,0x2e,0x04,
0x01,0x01,0x06,0x05,0x2e,0x04,0x04,0x01,0x23,0x04,0x00,0x66,0x10,0x04,0x01,0x05,
0x01,0x06,0x06,0x2e,0x05,0x02,0x01,0x2e,0x04,0x05,0x01,0x21,0x00,0x73,0x10,0x04,
0x4f,0x05,0x00,0x0b,0x06,0x3f,0x05,0x2e,0x04,0x05,0x01,0x37,0x04,0x00,0x00,0x00,
0x01,0x00,0x00,0x01,0x20,0x00,0x00,0x00,0x06,0x00,0x02,0x3c,0x3c,0x00,0x00,0x01,
0x26,0x00,0x00,0x02,0x5b,0x5d,0x00,0x00,0x0c,0x6c,0x63,0x64,0x5f,0x6c,0x6f,0x63,
0x61,0x74,0x69,0x6f,0x6e,0x00,0x00,0x02,0x21,0x3d,0x00,0x00,0x08,0x6c,0x63,0x64,
0x5f,0x70,0x75,0x74,0x73,0x00,0x45,0x4e,0x44,0x00,0x00,0x00,0x00,0x08,
};



//================================================================
/*! タイマー割込ハンドラ
*/
CY_ISR(isr_Tick)
{
  mrbc_tick();
}


//================================================================
/*! HAL
*/
int hal_write(int fd, const void *buf, int nbytes)
{
#if 0
  static int flag_connect = 1;

  if( !USBUART_CDCIsReady() ) {
    if( !flag_connect ) return 0;

    // wait about 100 ms.
    for( int i = 0; i < 10; i++ ) {
      CyDelay( 10 );
      if( USBUART_CDCIsReady() ){
	flag_connect = 1;
	goto WRITE_OK;
      }
    }
    flag_connect = 0;
    return 0;
  }

 WRITE_OK:
  usbuart_write( buf, nbytes );
  return nbytes;

#else
  const char *p = buf;
  for( int i = 0; i < nbytes; i++ ) {
    CONS_PutChar( *p++ );
  }
  return nbytes;
#endif
}

int hal_flush(int fd)
{
  return 0;
}

int _write(int fd, const void *buf, int nbytes)
{
  return hal_write(fd, buf, nbytes);
}


//================================================================
/*! mruby/c methods
*/
//================================================================
/*! オンボードSW 現在状態の読み込み
*/
static void c_sw1_read(mrbc_vm *vm, mrbc_value v[], int argc)
{
  int sw1 = SW1_Read();
  SET_INT_RETURN(sw1);
}

//================================================================
/*! オンボードLED ON/OFF
*/
static void c_led1_write(mrbc_vm *vm, mrbc_value v[], int argc)
{
  LED1_Write(GET_INT_ARG(1));
}


//================================================================
/*! LCD表示場所指定
*/
static void c_lcd_location(mrbc_vm *vm, mrbc_value v[], int argc)
{
  int row = GET_INT_ARG(1);
  int col = GET_INT_ARG(2);

  lcd_location(row, col);
}


//================================================================
/*! LCD表示　1文字
*/
static void c_lcd_putc(mrbc_vm *vm, mrbc_value v[], int argc)
{
  int ch = GET_INT_ARG(1);

  lcd_putc( ch );
}

//================================================================
/*! LCD表示　文字列
*/
static void c_lcd_puts(mrbc_vm *vm, mrbc_value v[], int argc)
{
  lcd_write( mrbc_string_cstr(&v[1]), mrbc_string_size(&v[1]) );
}

//================================================================
/*! LCD表示　全消去
*/
static void c_lcd_clear(mrbc_vm *vm, mrbc_value v[], int argc)
{
  lcd_clear();
}

//================================================================
/*! LCD表示　カーソル表示 ON / OFF
*/
static void c_lcd_cursor_on(mrbc_vm *vm, mrbc_value v[], int argc)
{
  lcd_cursor_on( GET_INT_ARG(1) );
}

//================================================================
/*! LCD表示　ブリンク ON / OFF
*/
static void c_lcd_blink_on(mrbc_vm *vm, mrbc_value v[], int argc)
{
  lcd_blink_on( GET_INT_ARG(1) );
}


//================================================================
/*! LCD表示　CGRAM設定

  lcd_set_cgram( 1, "\x00\x01..." )
*/
static void c_lcd_set_cgram(mrbc_vm *vm, mrbc_value v[], int argc)
{
  int code = v[1].i;
  uint8_t *bitmap5x8 = (uint8_t *)mrbc_string_cstr(&v[2]);
  lcd_set_cgram( code, bitmap5x8 );
}


//================================================================
/*! メインボード上キーパッド　現在状態の読み込み
*/
static void c_keypad_read(mrbc_vm *vm, mrbc_value v[], int argc)
{
  int kpad = KEYPAD_Read();	// bitmapped
  SET_INT_RETURN(kpad);
}


//================================================================
/*! GPIO constructor

  gpio1 = GPIO.new( 1 )  # 1 to 5
*/
static void c_gpio_new(mrbc_vm *vm, mrbc_value v[], int argc)
{
  *v = mrbc_instance_new(vm, v->cls, sizeof(int));
  int n;
  if( mrbc_type(v[1]) == MRBC_TT_FIXNUM ) {
    n = mrbc_fixnum(v[1]);
  } else {
    n = -1;
  }

  *(int *)(v->instance->data) = n;
}


//================================================================
/*! GPIO setmode

  gpio1.setmode( mode )
*/
static void c_gpio_setmode(mrbc_vm *vm, mrbc_value v[], int argc)
{
  int pin_num = *((int *)v->instance->data);

  //  printf("PIN: %d\n", pin_num);

  // TODO
  // とりあえずモードは、0:入力 1:出力としておく
  int mode;
  switch( mrbc_fixnum(v[1]) ) {
  case 0: mode = PIN_DM_DIG_HIZ; break;
  case 1: mode = PIN_DM_STRONG;  break;
  default: goto ERROR_RETURN;
  }

  switch( pin_num ) {
  // (note) ch1 is shared with PWM1
  case 2: GRV_D2_SetDriveMode( mode ); break;
  case 3: GRV_D3_SetDriveMode( mode ); break;
  case 4: GRV_D4_SetDriveMode( mode ); break;
  case 5: GRV_D5_SetDriveMode( mode ); break;
  default: goto ERROR_RETURN;
  }

  SET_TRUE_RETURN();
  return;

 ERROR_RETURN:
  SET_FALSE_RETURN();
}


//================================================================
/*! GPIO read

  gpio1.read()
*/
static void c_gpio_read(mrbc_vm *vm, mrbc_value v[], int argc)
{
  int pin_num = *((int *)v->instance->data);
  int ret;

  switch( pin_num ) {
  // (note) ch1 is shared with PWM1
  case 2: ret = GRV_D2_Read(); break;
  case 3: ret = GRV_D3_Read(); break;
  case 4: ret = GRV_D4_Read(); break;
  case 5: ret = GRV_D5_Read(); break;
  default: goto ERROR_RETURN;
  }

  SET_INT_RETURN( ret );
  return;

 ERROR_RETURN:
  SET_NIL_RETURN();
}


//================================================================
/*! GPIO write

  gpio1.write( 0 or 1 )
*/
static void c_gpio_write(mrbc_vm *vm, mrbc_value v[], int argc)
{
  int pin_num = *((int *)v->instance->data);
  int data = !!mrbc_fixnum(v[1]);

  switch( pin_num ) {
  case 1:
    PWM1_WriteCompare( 0 );
    if( data ) {
      PWM1_SetCompareMode(PWM1__B_PWM__GREATER_THAN_OR_EQUAL_TO);
    } else {
      PWM1_SetCompareMode(PWM1__B_PWM__LESS_THAN);
    }

  case 2: GRV_D2_Write( data ); break;
  case 3: GRV_D3_Write( data ); break;
  case 4: GRV_D4_Write( data ); break;
  case 5: GRV_D5_Write( data ); break;
  default: goto ERROR_RETURN;
  }

  SET_TRUE_RETURN();
  return;

 ERROR_RETURN:
  SET_FALSE_RETURN();
}



//================================================================
/*! ADC constructor

  adc1 = ADC.new( 1 )  # 0 to 3
*/
static void c_adc_new(mrbc_vm *vm, mrbc_value v[], int argc)
{
  *v = mrbc_instance_new(vm, v->cls, sizeof(int16_t));
  int16_t n;
  if( mrbc_type(v[1]) == MRBC_TT_FIXNUM ) {
    n = mrbc_fixnum(v[1]);
  } else {
    n = -1;
  }

  *(int16_t *)(v->instance->data) = n;
}


//================================================================
/*! ADC read

  adc1.read()	# return voltage by Float
*/
static void c_adc_read(mrbc_vm *vm, mrbc_value v[], int argc)
{
  int ch = *((int16_t *)v->instance->data);

  GRV_AMux_1_Select( ch );
  GRV_ADC_1_StartConvert();
  GRV_ADC_1_IsEndConversion( GRV_ADC_1_WAIT_FOR_RESULT );

  SET_FLOAT_RETURN( 2.048 / 4096 * GRV_ADC_1_GetResult16() );
}


//================================================================
/*! ADC read_u16

  adc1.read_u16()	# return voltage by Float
*/
static void c_adc_read_u16(mrbc_vm *vm, mrbc_value v[], int argc)
{
  int ch = *((int16_t *)v->instance->data);

  GRV_AMux_1_Select( ch );
  GRV_ADC_1_StartConvert();
  GRV_ADC_1_IsEndConversion( GRV_ADC_1_WAIT_FOR_RESULT );

  SET_INT_RETURN( GRV_ADC_1_GetResult16() );
}


//================================================================
/*! PWM constructor

  pwm1 = PWM.new( n )  # n = 0 or 1
*/
static void c_pwm_new(mrbc_vm *vm, mrbc_value v[], int argc)
{
  *v = mrbc_instance_new(vm, v->cls, sizeof(uint16_t) * 3);
  uint16_t n;
  if( mrbc_type(v[1]) == MRBC_TT_FIXNUM ) {
    n = mrbc_fixnum(v[1]);
  } else {
    console_printf("Specify PWM channel 0 or 1.");
    return;
  }
  if( n > 1 ) {
    console_printf("Specify PWM channel 0 or 1.");
    return;
  }

  uint16_t *data = (uint16_t *)v->instance->data;
  data[0] = n;		// channel (0-1)
  data[1] = 0;		// period
  data[2] = 0x4000;	// duty    (0-0x8000)
}


//================================================================
/*! PWM 周波数設定

  pwm1.frequency( 1000 )
*/
static void c_pwm_frequency(mrbc_vm *vm, mrbc_value v[], int argc)
{
  uint16_t *data = (uint16_t *)v->instance->data;
  double freq;
  int duty, period, compare;

  switch( mrbc_type(v[1]) ) {
  case MRBC_TT_FIXNUM:
    freq = mrbc_fixnum(v[1]);
    break;
  case MRBC_TT_FLOAT:
    freq = mrbc_float(v[1]);
    break;
  default:
    console_printf("PWM#frequency needs fixnum or float.");
    return;
  }
  if( freq < 0 ) return;

  if( freq == 0 ) {
    period = 0;
  } else {
    period = PWM_FREQ / freq;
  }
  if( period > PWM_COUNT_MAX ) return;

  data[1] = period;
  duty = data[2];

  compare = period * duty / 0x8000;

  if( data[0] == 0 ) {
    PWM0_WritePeriod( period );
    PWM0_WriteCompare( compare );
  } else {
    PWM1_WritePeriod( period );
    PWM1_WriteCompare( compare );
  }
}

//================================================================
/*! PWM デューティー比設定

  pwm1.duty( 512 )	# 0 to 1024
  pwm1.duty( 0.5 )	# 0.0 to 1.0
*/
static void c_pwm_duty(mrbc_vm *vm, mrbc_value v[], int argc)
{
  uint16_t *data = (uint16_t *)v->instance->data;
  int duty, period, compare;

  switch( mrbc_type(v[1]) ) {
  case MRBC_TT_FIXNUM:
    duty = mrbc_fixnum(v[1]) * 32;  // input 0-1024  using 0-32768
    break;
  case MRBC_TT_FLOAT:
    duty = mrbc_float(v[1]) * 32768;
    break;
  default:
    console_printf("PWM#duty needs fixnum or float.");
    return;
  }
  if( duty < 0 ) return;
  if( duty > 0x8000 ) return;

  period = data[1];
  data[2] = duty;

  compare = period * duty / 0x8000;

  if( data[0] == 0 ) {
    PWM0_WritePeriod( period );
    PWM0_WriteCompare( compare );
  } else {
    PWM1_WritePeriod( period );
    PWM1_WriteCompare( compare );
  }
}

//================================================================
/*! PWM 周期設定
*/
static void c_pwm_period_us(mrbc_vm *vm, mrbc_value v[], int argc)
{
  uint16_t *data = (uint16_t *)v->instance->data;
  int duty, period, compare;

  period = GET_INT_ARG(1);
  if( period < 0 ) return;

  period = period * (PWM_FREQ / 1000) / 1000;
  if( period > PWM_COUNT_MAX ) return;

  data[1] = period;
  duty = data[2];

  compare = period * duty / 0x8000;

  if( data[0] == 0 ) {
    PWM0_WritePeriod( period );
    PWM0_WriteCompare( compare );
  } else {
    PWM1_WritePeriod( period );
    PWM1_WriteCompare( compare );
  }
}



//================================================================
/*! デバグ表示
*/
static void c_debugprint(mrbc_vm *vm, mrbc_value v[], int argc)
{
#if !defined(NDEBUG)
  void pqall(void);

  hal_disable_irq();
  for( int i = 0; i < 79; i++ ) {
    console_putchar('=');
  }
  console_putchar('\n');
  mrbc_alloc_print_memory_pool();

  pqall();

  struct MRBC_ALLOC_STATISTICS ms;
  mrbc_alloc_statistics( &ms );
  console_printf("Memory total:%d, used:%d, free:%d, fragment:%d\n",
		 ms.total, ms.used, ms.free, ms.fragmentation );

  int used;
  mrbc_symbol_statistics( &used );
  console_printf("Symbol table: %d/%d %d%% used.\n",
		 used, MAX_SYMBOLS_COUNT, 100 * used / MAX_SYMBOLS_COUNT );

  hal_enable_irq();
#endif
}


//================================================================
/*! define mruby/c method for on-board devices.
*/
static void define_other_device_methods(void)
{
  mrbc_define_method(0, 0, "sw1_read",   c_sw1_read);
  mrbc_define_method(0, 0, "led1_write", c_led1_write);
  mrbc_define_method(0, 0, "lcd_location", c_lcd_location);
  mrbc_define_method(0, 0, "lcd_putc", c_lcd_putc);
  mrbc_define_method(0, 0, "lcd_puts", c_lcd_puts);
  mrbc_define_method(0, 0, "lcd_clear", c_lcd_clear);
  mrbc_define_method(0, 0, "lcd_cursor_on", c_lcd_cursor_on);
  mrbc_define_method(0, 0, "lcd_blink_on", c_lcd_blink_on);
  mrbc_define_method(0, 0, "lcd_set_cgram", c_lcd_set_cgram);

  mrbc_define_method(0, 0, "keypad_read", c_keypad_read);

  mrbc_class *gpio = mrbc_define_class(0, "GPIO", 0);
  mrbc_define_method(0, gpio, "new", c_gpio_new);
  mrbc_define_method(0, gpio, "setmode", c_gpio_setmode);
  mrbc_define_method(0, gpio, "read", c_gpio_read);
  mrbc_define_method(0, gpio, "write", c_gpio_write);

  mrbc_class *adc = mrbc_define_class(0, "ADC", 0);
  mrbc_define_method(0, adc, "new", c_adc_new);
  mrbc_define_method(0, adc, "read", c_adc_read);
  mrbc_define_method(0, adc, "read_u16", c_adc_read_u16);

  mrbc_class *pwm = mrbc_define_class(0, "PWM", 0);
  mrbc_define_method(0, pwm, "new", c_pwm_new);
  mrbc_define_method(0, pwm, "frequency", c_pwm_frequency );
  mrbc_define_method(0, pwm, "duty", c_pwm_duty );
  mrbc_define_method(0, pwm, "period_us", c_pwm_period_us );

  mrbc_define_method(0, 0, "debugprint", c_debugprint);
}


//================================================================
/*! mruby/c main
*/
static void mrubyc_start(void)
{
  uint16_t *tbl_bytecode_size = (uint16_t *)mruby_bytecode;
  const uint8_t *bytecode = mruby_bytecode + sizeof(uint16_t) * MRBC_MAX_BYTECODES;

  for( int i = 0 ; i < MRBC_MAX_BYTECODES ; i++ ) {
    if( tbl_bytecode_size[i] == 0 ) break;
    mrbc_create_task( bytecode, 0 );
    bytecode += tbl_bytecode_size[i];
  }

  mrbc_run();
}



//================================================================
/*! main
*/
int main()
{
  /*
    initialize
  */
  CyGlobalIntEnable;
  isr_Tick_StartEx(isr_Tick);

  // on-board devices.
  Em_EEPROM_Start();
  Opamp_1_Start();
  PWM0_Start();
  PWM1_Start();
  PWM1_SetCompareMode(PWM1__B_PWM__LESS_THAN);
  CONS_Start();

  mrbc_monitor_init();
  lcd_init();

  // grove devices.
  GRV_AMux_1_Start();
  GRV_ADC_1_Start();

  // init mruby/c vm's
  mrbc_init(memory_pool, MEMORY_SIZE);
  mrbc_init_class_i2c(0);
  mrbc_init_class_uart(0);	// -DMRBC_NUM_UART=2
  mrbc_init_class_spi(0);
  mrbc_init_class_eeprom(0);
  define_other_device_methods();

  console_print("\r\n\x1b(B\x1b)B\x1b[0m\x1b[2JStart system.\n");
  lcd_location( 0, 0 );
  lcd_puts("mruby/c devkit 02");
  lcd_location( 1, 5 );
  lcd_puts("firm rev 1.0.0");
  lcd_location( 2, 5 );
  lcd_puts("mruby/c ver 3.2");

  /*
    main
  */
  int flag_monitor_or_exec;
  flag_monitor_or_exec = mrbc_monitor_or_exec();

  while( 1 ) {
    if( flag_monitor_or_exec == 0 ) {
      // start mruby/c VM
      lcd_clear();
      console_print("Start mruby/c program.\n");
      mrubyc_start();

      lcd_location( 3, 15 );
      lcd_puts( "done" );
      lcd_blink_on( 1 );
      console_print("\r\nmruby/c done.\n");
    }

    flag_monitor_or_exec = mrbc_monitor_run();
  }
}

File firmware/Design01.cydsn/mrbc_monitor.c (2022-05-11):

/*! @file
  @brief
  mruby/c monitor (IREP writer) for Cypress CY8CKIT-059, PSoC5LP
  using USBUART.

  <pre>
  Copyright (C) 2018-2020 Kyushu Institute of Technology.
  Copyright (C) 2018-2020 Shimane IT Open-Innovation Center.

  This file is distributed under BSD 3-Clause License.

  </pre>
*/

/* Flash ROM structure.
  (e.g. MRBC_MAX_BYTECODES = 4)
 0000 size1	(uint16_t * 4)
 0002 size2
 0004 size3
 0006 size4
 0008 IREP1	(size1 bytes)
 xxxx IREP2	(size2 bytes)
 xxxx IREP3	(size3 bytes)
 xxxx IREP4	(size4 bytes)
*/


#include <project.h>
#include <stdlib.h>

#include "mrbc_monitor.h"

#define MRUBYC_VERSION_STRING   "mruby/c v2.1 PSoC5LP"
#define USBUART_BUFFER_SIZE 64	// max 64bytes. see USBFS manual.



//================================================================
/*! USBUART read buffer.
*/
static struct {
  uint8_t buf[USBUART_BUFFER_SIZE * 2 + 1];
  uint8_t flag_can_read_line;
  uint8_t *p_buf_w;
} usbuart_;


//================================================================
/*! tiny int to string conversion.
*/
static char *tiny_itoa( char *buf, int n )
{
  char *p1 = buf;

  do {
    int d = n % 10;
    *p1++ = '0' + d;
    n /= 10;
  } while( n != 0 );

  *p1-- = 0;

  char *p2 = buf;
  while( p2 < p1 ) {
    int ch = *p2;
    *p2++ = *p1;
    *p1-- = ch;
  }

  return buf;
}



//================================================================
/*! USBUART buffer clear.
*/
void usbuart_clear(void)
{
  usbuart_.p_buf_w = usbuart_.buf;
  usbuart_.flag_can_read_line = 0;
}


//================================================================
/*! USBUART Can read line ?

  @retval	true if a line of data can be read.
*/
int usbuart_can_read_line(void)
{
  return usbuart_.flag_can_read_line;
}


//================================================================
/*! USBUART return the byte size of buffer data.

  @retval	size
*/
int usbuart_size(void)
{
  return usbuart_.p_buf_w - usbuart_.buf;
}


//================================================================
/*! USBUART return the pointer to read buffer.

  @retval	pointer to read buffer.
*/
char * usbuart_cstr(void)
{
  return (char*)usbuart_.buf;
}


//================================================================
/*! USBUART put string

  @param
*/
void usbuart_put_string( const char *s )
{
  //  To be sure that the previous data has finished sending.
  while( !USBUART_CDCIsReady() ) { /* busy loop. */ }

  USBUART_PutString(s);
}


//================================================================
/*! USBUART binary read.

  @param  buf	pointer to read buffer.
  @param  nbyte	maximum reading byte length.
  @retval	read length.
*/
int usbuart_read( void *buf, int nbyte )
{
  int len = nbyte;

  while( len > 0 ) {
    if( usbuart_size() == 0 ) {
      if( usbuart_event() < 0 ) {
	return 0;
      }
      continue;
    }

    int copy_size = usbuart_size() < len ? usbuart_size() : len;
    int remain = usbuart_size() - copy_size;

    memcpy( buf, usbuart_.buf, copy_size );
    if( remain > 0 ) {
      memmove( usbuart_.buf, usbuart_.buf + copy_size, remain );
      usbuart_.p_buf_w = usbuart_.buf + remain;
    } else {
      usbuart_clear();
    }

    buf += copy_size;
    len -= copy_size;
  }

  return nbyte;
}


//================================================================
/*! USBUART binary write.

  @param  buf	pointer to write data.
  @param  nbyte	write byte size.
*/
void usbuart_write( const char *buf, int nbyte )
{
  while( nbyte > 0 ) {
    //  To be sure that the previous data has finished sending.
    while( !USBUART_CDCIsReady() ) { /* busy loop. */ }

    int size = (nbyte < USBUART_BUFFER_SIZE) ? nbyte : USBUART_BUFFER_SIZE;
    USBUART_PutData( (uint8_t*)buf, size );
    buf += USBUART_BUFFER_SIZE;
    nbyte -= USBUART_BUFFER_SIZE;
  }

  if( nbyte == 0 ) {
    /* Send zero-length packet to PC. */
    while( !USBUART_CDCIsReady() ) { /* busy loop. */ }
    USBUART_PutData(NULL, 0);
  }
}


//================================================================
/*! USBUART event handler.

  @retval
*/
int usbuart_event(void)
{
  if( USBUART_IsConfigurationChanged() ) {
    /* Initialize IN endpoints when device is configured. */
    if( USBUART_GetConfiguration() ) {
      /* Enumeration is done, enable OUT endpoint to receive data from host. */
      USBUART_CDC_Init();
    }

    return 1;
  }

  if( !USBUART_GetConfiguration() ) {
    return -1;
  }

  if( USBUART_DataIsReady() ) {
    int count = USBUART_GetCount();
    int remain = sizeof(usbuart_.buf) - usbuart_size() - 1;

    if( count > remain ) count = remain;
    USBUART_GetData( usbuart_.p_buf_w, count );

    for( ; count != 0; count-- ) {
      if( *usbuart_.p_buf_w++ == '\n' ) {
	usbuart_.flag_can_read_line = 1;
      }
    }
    *usbuart_.p_buf_w = '\0';

    // TODO check buffer full
    return 2;
  }

  return 0;
}



//================================================================
/*! write bytecode

  @param  size	size of bytecode
  @retval 0	OK.
  @retval 1	number of programs overflow.
  @retval 2	total bytecode size overflow.
*/
static int write_bytecode( uint16_t size )
{
  static const uint8_t *FLASH_ADDR_END = mruby_bytecode + MRBC_SIZE_IREP_STRAGE;
  uint16_t tbl_bytecode_size[MRBC_MAX_BYTECODES];
  const uint8_t *flash_addr = mruby_bytecode + sizeof(tbl_bytecode_size);
  int used_idx;

  memcpy( tbl_bytecode_size, mruby_bytecode, sizeof(tbl_bytecode_size));

  for( used_idx = 0; used_idx < MRBC_MAX_BYTECODES; used_idx++ ) {
    if( tbl_bytecode_size[used_idx] == 0 ) break;
    flash_addr += tbl_bytecode_size[used_idx];
  }

  if( used_idx >= MRBC_MAX_BYTECODES ) return 1;
  if( flash_addr + size > FLASH_ADDR_END ) return 2;

  tbl_bytecode_size[used_idx] = size;

  cystatus status = Em_EEPROM_Write((uint8_t *)tbl_bytecode_size,
				    mruby_bytecode, sizeof(tbl_bytecode_size));
  if (CYRET_SUCCESS != status) {
    CONS_PutString("Em EEPROM size table write error.\r\n");
    while (1) { /* Will stay here */ }
  }

  while( size > 0 ) {
    uint8_t buf[CY_FLASH_SIZEOF_ROW];
    int read_size = size < sizeof(buf) ? size : sizeof(buf);
    read_size = usbuart_read( buf, read_size );
    status = Em_EEPROM_Write(buf, flash_addr, read_size);

    if (CYRET_SUCCESS != status) {
      CONS_PutString("Em EEPROM error3\r\n");
      while (1) { /* Will stay here */ }
    }

    size -= read_size;
    flash_addr += read_size;
  }

  usbuart_clear();

  return 0;
}


//================================================================
/*! clear bytecode
*/
static int clear_bytecode( void )
{
  uint16_t tbl_bytecode_size[MRBC_MAX_BYTECODES] = {0};

  cystatus status = Em_EEPROM_Write((uint8_t *)tbl_bytecode_size,
				    mruby_bytecode, sizeof(tbl_bytecode_size));
  if (CYRET_SUCCESS != status) {
    CONS_PutString("Em EEPROM size table write error.\r\n");
    while (1) { /* Will stay here */ }
  }

  return 0;
}
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

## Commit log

2021-11-25 add files.
    [PARTS_LIST_190726D.csv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]
2021-12-01 add ADXL345 sample.
2021-12-02 add breakout board image.
2021-12-03 add LED Bar files.
2021-12-27 コンソールを特別扱いするのを止めて UART_0 にリネームし、mruby/cから UARTクラス経由でも使えるようにした。
2022-05-10 Revert "コンソールを特別扱いするのを止めて UART_0 にリネームし、mruby/cから UARTクラス経由でも使えるようにした。"
    This reverts commit 77f8af8a6ebd123f5109c37fe4c639a108826059.
    [main.c, mrbc_monitor.c]
